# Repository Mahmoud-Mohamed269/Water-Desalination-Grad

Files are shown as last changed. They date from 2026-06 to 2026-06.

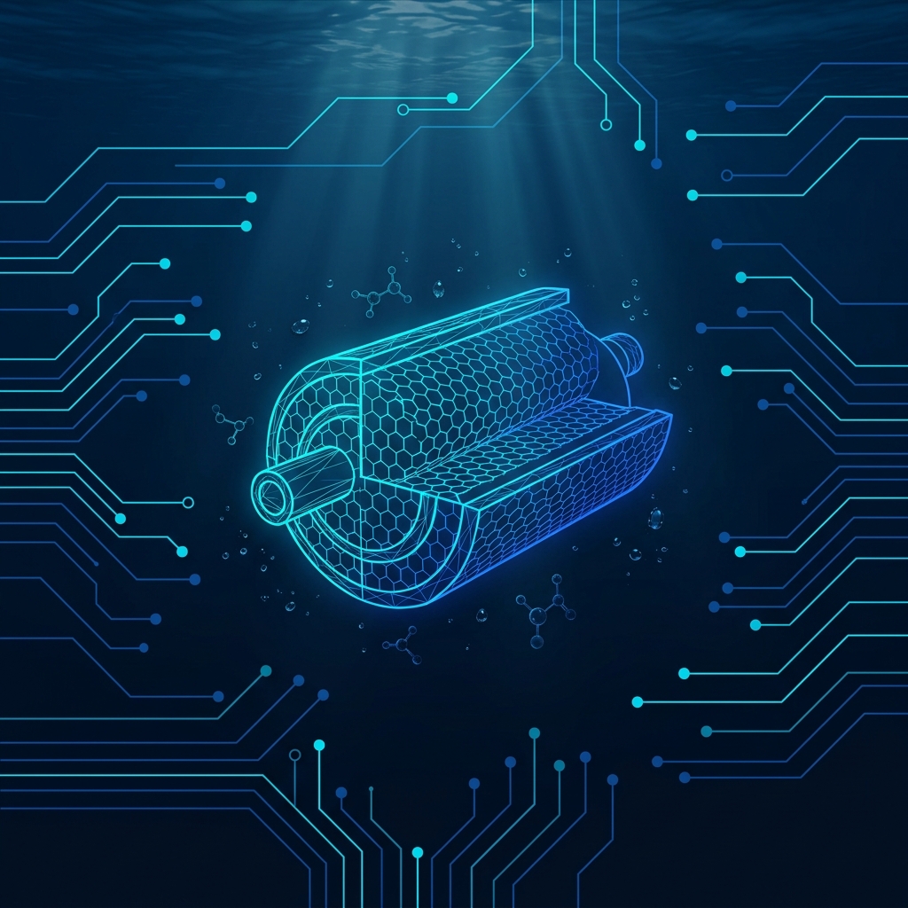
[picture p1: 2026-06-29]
dashboard/src/assets/images/dashboard_bg.png

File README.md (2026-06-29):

# 🌊 AquaMonitor — Smart Water Desalination Monitoring System

A full-stack IoT monitoring and analytics platform for Reverse Osmosis (RO) desalination systems. Combines ESP32 edge nodes, Firebase real-time cloud storage, a FastAPI ML backend, a web dashboard, and a cross-platform mobile app.

---

## 🏗️ System Architecture

```
┌─────────────┐   ESP-NOW    ┌──────────────┐   Firebase RTDB   ┌─────────────┐
│  Node 1     │ ──────────── │   Main Hub   │ ────────────────── │   Firebase  │
│  (Water Q.) │              │   (ESP32)    │                    │  Realtime   │
│  Node 2     │              │              │                    │  Database   │
│  (Environ.) │              └──────┬───────┘                    └──────┬──────┘
└─────────────┘                     │ BLE                               │
                              ┌─────▼──────┐                     ┌──────▼──────┐
                              │ Mobile App │  ←── HTTP sync ────▶│  FastAPI    │
                              │  (Python/  │                      │  Backend    │
                              │   Flet)    │                      │  + ML Models│
                              └────────────┘                      └──────┬──────┘
                                                                         │
                                                                  ┌──────▼──────┐
                                                                  │    Web      │
                                                                  │  Dashboard  │
                                                                  │  (HTML/JS)  │
                                                                  └─────────────┘
```

---

## 📁 Project Structure

```
Water Desalination/
├── Node1_WaterQuality/     # ESP32 firmware — pH, TDS, turbidity, pressure, flow
├── Node2_Environment/      # ESP32 firmware — temperature, humidity, gas, ultrasonic
├── Main_Hub/               # ESP32 firmware — ESP-NOW receiver, BLE server, Firebase uploader
├── backend/                # FastAPI backend — ML predictions, alerts, Firebase proxy
│   ├── app/api/v1/         # REST endpoints (sensors, predict, alerts, chat, status)
│   ├── app/core/           # Config, Firebase client, security
│   ├── app/services/       # ML inference service
│   ├── ml/                 # Trained .pkl model files
│   ├── Procfile            # Railway deployment
│   └── railway.json        # Railway config
├── dashboard/web/          # Web dashboard (HTML + CSS + JS, Firebase direct)
├── mobile/src/             # Flet mobile app (Python)
│   ├── pages/              # Live, History, Alerts, WiFi, Settings
│   ├── ble/                # Real + Virtual BLE client
│   └── db/                 # SQLite offline storage + sync
└── Water Desalination.html # Standalone single-file web dashboard
```

---

## 🔧 Hardware (Bill of Materials)

| Component | Model | Qty | Node |
|---|---|---|---|
| Microcontroller | ESP32 38-pin | 3 | All |
| pH Sensor | Analog pH Kit (BNC) | 2 | Node 1 (feed + permeate) |
| TDS Sensor | TDS Meter V1.0 | 2 | Node 1 (feed + permeate) |
| Turbidity Sensor | Analog module | 1 | Node 1 |
| Pressure Sensor | G1/4 0–1.2 MPa analog | 1 | Node 1 |
| Temperature Sensor | DS18B20 | 2 | Node 1 |
| Flow Sensor | YF-S201 | 2 | Node 1 (feed + permeate) |
| Water Level Sensor | XKC-Y25 (non-contact) | 2 | Node 1 |
| Relay Module | 2-channel 5V | 1 | Node 1 (pump + valve) |
| Temp + Humidity | DHT22 | 1 | Node 2 |
| Gas Sensor | MQ series | 2 | Node 2 |
| Ultrasonic | HC-SR04 | 2 | Node 2 |
| TFT Display | 5" SPI | 1 | Main Hub |

---

## 🚀 Setup Instructions

### 1. Firebase Setup
1. Create a project at [console.firebase.google.com](https://console.firebase.google.com)
2. Enable **Realtime Database** (Europe West region)
3. Download the **service account JSON** → save as `backend/serviceAccountKey.json`
4. Copy your database URL to `backend/.env`:
   ```
   FIREBASE_DATABASE_URL=https://your-project-rtdb.europe-west1.firebasedatabase.app
   ```

### 2. Flash Hardware
```bash
# In Arduino IDE:
# 1. Flash Main_Hub to the hub ESP32 first — note its MAC address from Serial Monitor
# 2. Update hubAddress in Node1/config.h and Node2/config.h
# 3. Flash Node 1 and Node 2
# 4. Open Serial Monitor (115200 baud) — you should see:
#    [ESP-NOW] Node 1 data received
#    [Firebase] Live data pushed OK
```

### 3. Run the Backend
```bash
cd backend
pip install -r requirements.txt
uvicorn main:app --reload
# API docs: http://127.0.0.1:8000/docs
```

### 4. Open the Web Dashboard
```bash
# Option A — standalone file (no server needed):
open "Water Desalination.html"

# Option B — from the dashboard folder:
open dashboard/web/index.html
```

### 5. Run the Mobile App
```bash
cd mobile/src
pip install flet bleak requests
python main.py
```
- Use **Settings** tab to toggle Virtual BLE (for testing without hardware)
- Use **WiFi** tab to provision WiFi credentials to the Hub over BLE

---

## ☁️ Cloud Deployment (Vercel)

Full step-by-step guide: **[phase10_cloud_deployment.md](phase10_cloud_deployment.md)**

### Quick Summary

**1. Encode your Firebase service account as base64 (PowerShell):**
```powershell
[Convert]::ToBase64String([IO.File]::ReadAllBytes("backend\serviceAccountKey.json")) | Set-Clipboard
```

**2. Push to GitHub, then import to [vercel.com](https://vercel.com):**
- Set Root Directory → `backend`
- Framework Preset → `Other`

**3. Add these Environment Variables in Vercel:**
| Variable | Value |
|---|---|
| `FIREBASE_DATABASE_URL` | Your Firebase RTDB URL |
| `FIREBASE_SERVICE_ACCOUNT_BASE64` | Paste the base64 string from step 1 |
| `GEMINI_API_KEY` | Your Gemini API key |
| `API_KEY` | Your chosen API key |

**4. Deploy → get your URL → update mobile app Settings.**

> See [phase10_cloud_deployment.md](phase10_cloud_deployment.md) for the full tutorial including verification steps and troubleshooting.

---

## 🔐 Security

| Layer | Mechanism |
|---|---|
| Backend write endpoints | `X-API-Key` header required |
| Firebase Database | Security Rules (auth-gated in production) |
| Secrets | `.env` file only — `.gitignore`'d |
| CORS | Restricted to known origins |

The API key is set via `API_KEY` in `backend/.env`. The mobile app and ESP32 Hub include it in `X-API-Key` headers for POST requests.

---

## 🤖 ML Models

Two Random Forest models trained on synthetic RO system data:

| Model | Output | File |
|---|---|---|
| Water Quality Classifier | good / acceptable / poor / bad | `water_quality_rf.pkl` |
| Membrane Status Classifier | good / warning / critical / fouled | `membrane_status_rf.pkl` |

**Input features (13):** pH before/after, TDS before/after, Turbidity before/after, Temperature before/after, Pressure, Efficiency (recovery rate), TDS Reduction %, Turbidity Reduction %, pH Change.

**Auto-prediction endpoint:** `GET /api/v1/predict/run` — fetches live Firebase data and derives all features automatically. Call it from the mobile app's Dashboard → ML Analysis → ↻ button.

---

## 📡 API Reference

| Method | Endpoint | Auth | Description |
|---|---|---|---|
| GET | `/api/v1/sensors/live` | Public | Latest live sensor snapshot |
| GET | `/api/v1/sensors/history` | Public | Last N historical readings |
| POST | `/api/v1/sensors/ingest` | API Key | Push sensor data to Firebase |
| GET | `/api/v1/predict/run` | Public | Auto-run ML from live data |
| POST | `/api/v1/predict/` | Public | Manual ML prediction |
| GET | `/api/v1/alerts/history` | Public | Recent alerts |
| POST | `/api/v1/alerts/evaluate` | Public | Evaluate snapshot against thresholds |
| POST | `/api/v1/chat/` | Public | Gemini AI chatbot |
| GET | `/api/v1/status/` | Public | System health |

Full interactive docs: `http://127.0.0.1:8000/docs`

---

## 🛠️ Development

```bash
# Backend tests
cd backend
python -m pytest

# Mobile app (desktop mode)
cd mobile/src
python main.py

# Generate synthetic training data
python generate_data.py

# Retrain ML models
python ML_models.py
```

---

## 📋 Phase Completion Status

| Phase | Description | Status |
|---|---|---|
| 1 | Requirements & Architecture | ✅ |
| 2 | Hardware Design & BOM | ✅ |
| 3 | ESP32 Firmware | ✅ |
| 4 | FastAPI Backend + ML | ✅ |
| 5 | Deployment Guide | ✅ |
| 6 | Hardware Assembly & Real Testing | ✅ Node 1 + Hub verified |
| 8 | Mobile App Polish | ✅ |
| 9 | Security (API Key) | ✅ |
| 10 | Cloud Deployment (Railway) | ⏳ Ready to deploy |
| 11 | Documentation | ✅ |

---

## 👥 Team

Built as part of the TVI Water Desalination Monitoring Project.

---

*Last updated: June 2026*

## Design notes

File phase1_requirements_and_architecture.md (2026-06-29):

# 🌊 Smart Water Desalination Monitoring & Analytics System
## Phase 1 — Requirements Analysis and System Architecture

> [!NOTE]
> **Design Decisions Log** (Updated after user review)
> - ✅ ML Dataset: Will be synthetically generated in Phase 11 (no real dataset required to start)
> - ✅ Flow Sensor (YF-S201): Included — required for Recovery Rate calculation and pump failure detection
> - ✅ Solenoid Valve: Included — enables automated safety shutoff and remote control
> - ✅ Power Mode: Battery/Solar — ESP32 uses Deep Sleep with dual wake sources (water level sensor + dashboard command)

---

## 📋 Table of Contents

1. [Objectives](#objectives)
2. [Theory](#theory)
3. [Detailed System Explanation](#detailed-system-explanation)
4. [System Architecture Design](#system-architecture-design)
5. [Technology Stack Justification](#technology-stack-justification)
6. [Firebase Database Schema](#firebase-database-schema)
7. [Folder Structure](#folder-structure)
8. [Data Flow Diagram](#data-flow-diagram)
9. [Sensor Specifications & Requirements](#sensor-specifications--requirements)
10. [Non-Functional Requirements](#non-functional-requirements)
11. [Validation Checklist](#validation-checklist)
12. [Common Errors & Troubleshooting](#common-errors--troubleshooting)
13. [Best Practices](#best-practices)

---

## 1. Objectives

| # | Objective | Priority |
|---|---|---|
| 1 | Define all functional and non-functional system requirements | 🔴 Critical |
| 2 | Design the complete multi-layer system architecture | 🔴 Critical |
| 3 | Define sensor data models and measurement ranges | 🔴 Critical |
| 4 | Design the Firebase Realtime Database schema | 🔴 Critical |
| 5 | Define the project folder structure (monorepo) | 🔴 Critical |
| 6 | Define communication protocols between all layers | 🟠 High |
| 7 | Establish data quality and filtering requirements | 🟠 High |
| 8 | Define ML prediction targets and thresholds | 🟠 High |
| 9 | Establish security and authentication model | 🟡 Medium |
| 10 | Define deployment strategy per component | 🟡 Medium |

---

## 2. Theory

### 2.1 Reverse Osmosis (RO) Desalination — Engineering Overview

Reverse Osmosis is a pressure-driven membrane separation process. Feed water is pushed through a semi-permeable membrane that rejects dissolved solids, ions, and organic molecules, producing permeate (purified water) and concentrate (brine reject).

**Key Physical Parameters:**

| Parameter | Symbol | Unit | Role in RO |
|---|---|---|---|
| pH | pH | 0–14 | Membrane longevity, scaling potential |
| TDS | TDS | mg/L (ppm) | Rejection efficiency measurement |
| Turbidity | NTU | NTU | Pre-filter fouling, feed quality |
| Temperature | T | °C | Membrane permeability, reaction kinetics |
| Pressure | P | bar / PSI | Driving force for permeation |
| Flow Rate | Q | L/min | Recovery rate, system throughput — **Required for efficiency calculations** |
| Water Level | L | % / cm | Tank management, feed availability — **Also used as wake/sleep trigger** |
| EC (Optional) | EC | µS/cm | Salinity proxy, conductivity |

**Critical RO Ratios:**

```
Recovery Rate (%) = (Permeate Flow / Feed Flow) × 100       ← Requires YF-S201 Flow Sensor
Rejection Rate (%) = (1 - Permeate TDS / Feed TDS) × 100   ← Requires TDS Sensor
Salt Passage (%) = (Permeate TDS / Feed TDS) × 100
```

> **Why the Flow Sensor is non-negotiable:** Recovery Rate is the primary KPI of any RO system. Without it, you cannot determine if your system is operating efficiently or if the membrane is degrading. The YF-S201 (~$3) is the cheapest and most impactful sensor in the system.

> **Why the Solenoid Valve is essential for automation:** Without the solenoid valve, your system can only *alert* you to problems. With it, the system can automatically *respond* — for example, immediately closing when TDS spikes above safe levels, protecting downstream equipment and users. This is the difference between a monitoring system and a control system.

**Typical Target Values for Potable Water (WHO Standards):**

| Parameter | Acceptable Range | Alert Threshold |
|---|---|---|
| pH | 6.5 – 8.5 | < 6.0 or > 9.0 |
| TDS | < 500 mg/L | > 1000 mg/L |
| Turbidity | < 1 NTU | > 4 NTU |
| Temperature | 5 – 30°C | > 40°C |
| Pressure (Feed) | 3 – 8 bar | > 10 bar |

### 2.2 IoT Architecture Patterns

This system uses the **Edge-to-Cloud** IoT architecture:

```
Edge Layer     →   Transport Layer   →   Cloud Layer   →   Application Layer
(ESP32 + Sensors)  (WiFi + MQTT/HTTP)  (Firebase)      (FastAPI + Flet + ML)
```

**Why Edge-to-Cloud?**
- ESP32 handles local data acquisition and preliminary filtering
- Cloud handles persistence, analytics, and multi-client access
- Application layer handles visualization, AI, and prediction

### 2.3 Machine Learning in Water Quality

Random Forest is chosen because:
- Handles non-linear relationships between sensor parameters
- Robust to outliers (critical when sensors malfunction)
- Provides feature importance (explains WHY a prediction was made)
- Works well with tabular sensor data
- Low inference latency (<1ms for 100 trees on sensor data)
- scikit-learn implementation is production-ready

> [!IMPORTANT]
> **No real dataset available at project start.** A realistic synthetic dataset will be generated in Phase 11 using:
> - RO membrane physics equations (rejection rate curves, fouling models)
> - WHO and EPA water quality standards as label boundaries
> - Gaussian sensor noise injection (based on datasheet accuracy specs)
> - Fault scenario injection (membrane fouling, sensor drift, pump cavitation)
> - The synthetic dataset will be used for initial training, then the model will be retrained and fine-tuned using real data collected by the system after deployment.

---

## 3. Detailed System Explanation

### 3.1 System Layers

```mermaid
graph TD
    subgraph "Layer 1: Physical / Sensing Layer (Edge Nodes)"
        S1[Node 1: Water Quality]
        S2[Node 2: Environment]
    end

    subgraph "Layer 2: Local Hub Layer (Main ESP32)"
        Hub[Main Hub: Comms & Display]
    end

    subgraph "Layer 3: Mobile / Offline Layer"
        App[Flet Mobile App]
        LocalDB[(SQLite Local DB)]
    end

    subgraph "Layer 4: Cloud Data Layer"
        FB[(Firebase Realtime DB)]
    end

    subgraph "Layer 5: Backend / API Layer (FastAPI)"
        API[FastAPI + ML Models]
    end

    S1 -- "ESP-NOW (Broadcast)" --> Hub
    S2 -- "ESP-NOW (Broadcast)" --> Hub
    Hub -- "BLE (Offline Sync)" --> App
    Hub -- "WiFi (Live Upload)" --> FB
    App -- "Local Storage" --> LocalDB
    App -- "WiFi (Background Sync)" --> API
    API -- "Ingest / Read" --> FB
```

### 3.2 ESP32 Pin Assignment Plan

> [!NOTE]
> This is the high-level plan for the 3-node architecture. Full pinouts will be finalized in Phase 2 (Hardware Design).

**Node 1 (Water Quality - ESP32 38-pin):**
- pH Feed & Permeate (GPIO34=pH Feed, GPIO36=pH Permeate) — ADC1 only
- TDS Feed & Permeate (GPIO35=TDS Feed, GPIO39=TDS Permeate) — ADC1 only
- Turbidity Feed (GPIO32) — ADC1 only, via 10kΩ/20kΩ voltage divider
- Pressure Feed / G1/4 (GPIO33) — ADC1 only, via 10kΩ/20kΩ voltage divider
- Temperature Feed & Permeate (GPIO4, DS18B20 shared OneWire bus)
- Flow Sensor Feed (GPIO18, interrupt), Flow Permeate (GPIO27, digital interrupt only — ADC2 pin but NOT used for analogRead, safe with WiFi)
- Level Sensors: Feed (GPIO5), Product (GPIO19)
- Relays: Pump (GPIO26), Valve (GPIO25)

**Node 2 (Environment & Fans - ESP32 38-pin):**
- 2x Ultrasonic (Trig/Echo digital pins)
- 1x DHT22 (Digital pin)
- 2x Gas Sensors (ADC1 pins)
- 2x Water Temp (DS18B20 on GPIO4)
- 3x Fans (Relay output pins)

**Main Hub (Display & Comms - ESP32 38-pin):**
- 5-inch SPI TFT Display (MOSI, SCK, CS, DC, RST)
- No analog sensors attached (avoids WiFi/ADC2 conflicts entirely)

> [!IMPORTANT]
> **Mobile App Offline Sync Architecture**
> - The Main ESP32 constantly streams data to the Mobile App via BLE.
> - The App stores data in a local SQLite DB.
> - When internet is available, the App syncs the local DB to Firebase, ensuring zero data loss during WiFi outages.

---

## 4. System Architecture Design

### 4.1 Communication Flowcharts

**Main Hub (Display & Comms) Flowchart**
```mermaid
graph TD
    Start((Start)) --> Init[Init WiFi, NTP, BLE, ESP-NOW, Firebase]
    Init --> ReceiveLoop
    
    ReceiveLoop[Listen for ESP-NOW from Nodes 1 & 2] --> |Data Received| Merge[Merge into JSON Payload]
    Merge --> UpdateDisplay[Update LCD Display]
    UpdateDisplay --> CheckApp{Mobile App Connected via BLE?}
    
    CheckApp -->|Yes| SendBLE[Stream JSON to App]
    CheckApp -->|No| CheckWiFi{WiFi Connected?}
    
    SendBLE --> CheckWiFi
    CheckWiFi -->|Yes| Sync[Upload JSON directly to Firebase RTDB]
    CheckWiFi -->|No| ReceiveLoop
    Sync --> ReceiveLoop
```

**Mobile App (Offline Sync) Flowchart**
```mermaid
graph TD
    Start((App Open)) --> ConnectBLE[Connect to Main Hub via BLE]
    ConnectBLE --> ReceiveData[Receive Merged JSON Data]
    ReceiveData --> StoreLocal[(Store in Local SQLite DB)]
    StoreLocal --> CheckNet{Phone has Internet?}
    
    CheckNet -->|Yes| Sync[Upload Pending Data to FastAPI Backend]
    Sync --> ReceiveData
    CheckNet -->|No| ReceiveData
```

### 4.2 Communication Protocols

| Layer | Protocol | Format | Frequency |
|---|---|---|---|
| Nodes → Main Hub | ESP-NOW | C-Struct | Every 5 sec |
| Main Hub → App | Bluetooth (BLE) | JSON | Every 3 sec |
| Main Hub → Firebase | HTTP / RTDB | JSON | Every 5 sec |
| App → Backend | HTTP POST | JSON | Background Sync |
| Backend → Firebase | Firebase Admin SDK | JSON | On-demand / ingest |
| FastAPI → Dashboard | HTTP GET/POST | JSON | Real-time polling |
| Backend → Gemini | HTTPS | JSON | On-demand chatbot |
| FastAPI → ML Service | Internal Python | Array | On-demand prediction |

---

## 5. Technology Stack Justification

### 5.1 Why ESP32S?
- Dual-core Xtensa LX6 @ 240 MHz — handles sensor reading + WiFi simultaneously
- Built-in WiFi + Bluetooth
- 18 ADC channels (we use ADC1 only during WiFi)
- 4MB flash, 520KB SRAM — sufficient for firmware + buffers
- Low cost, wide community support

### 5.2 Why Firebase Realtime Database?
- Real-time push to all connected clients simultaneously
- JSON tree structure maps naturally to sensor readings
- Built-in security rules
- Free tier: 1GB storage, 10GB/month transfer
- Native SDK for Python, JavaScript, mobile

### 5.3 Why FastAPI?
- Async-first (handles concurrent sensor reads + client requests)
- Auto-generates OpenAPI documentation
- Native Pydantic validation (enforces data schemas)
- Easy ML model integration (Python-native)
- High performance (comparable to Node.js)

### 5.4 Why Flet?
- Write once, run on Web + Android + iOS + Desktop (Python)
- Flutter rendering engine → native-quality UI
- Firebase integration via Python SDK
- Shared codebase for dashboard and mobile app

### 5.5 Why Random Forest?
- No need for feature scaling (unlike SVM, neural nets)
- Interpretable (feature importance)
- Handles missing data gracefully
- Fast inference (<1ms for 100 trees on sensor data)
- scikit-learn implementation is production-ready

### 5.6 Why Google Gemini API?
- Multimodal (can interpret sensor charts + text)
- Domain knowledge of water treatment
- Structured output support (JSON responses)
- Function calling (can query Firebase directly)

---

## 6. Firebase Database Schema

### 6.1 Complete Schema Design

```json
{
  "devices": {
    "device_001": {
      "info": {
        "name": "RO Unit Alpha",
        "location": "Plant A - Zone 1",
        "firmware_version": "1.0.0",
        "registered_at": "2024-01-01T00:00:00Z",
        "last_seen": "2024-01-01T12:00:00Z",
        "status": "online"
      },
      "config": {
        "sampling_interval_ms": 5000,
        "alert_thresholds": {
          "ph_min": 6.5,
          "ph_max": 8.5,
          "tds_max": 1000,
          "turbidity_max": 4.0,
          "temperature_max": 40.0,
          "pressure_max": 10.0,
          "flow_rate_min": 0.5
        },
        "filtering": {
          "algorithm": "kalman",
          "window_size": 10
        }
      },
      "live_data": {
        "ph_feed": 7.2,
        "ph_permeate": 6.9,
        "tds_feed": 850,
        "tds_permeate": 12,
        "turbidity_feed": 0.8,
        "temperature_feed": 24.5,
        "temperature_permeate": 24.2,
        "pressure_feed": 4.2,
        "flow_rate_feed": 2.5,
        "flow_rate_permeate": 1.8,
        "recovery_rate": 72.0,
        "rejection_rate": 98.6,
        "water_level_feed_tank": 100,
        "water_level_product_tank": 0,
        "pump_status": "running",
        "valve_status": "open",
        "tank1_level_cm": 45.5,
        "tank2_level_cm": 20.0,
        "ambient_temp": 32.0,
        "ambient_humidity": 65.0,
        "gas_1_ppm": 400.0,
        "gas_2_ppm": 350.0,
        "water_temp_1": 25.0,
        "water_temp_2": 26.0,
        "fan_1_status": true,
        "fan_2_status": false,
        "fan_3_status": false,
        "timestamp": "2024-01-01T12:00:00Z",
        "uptime_seconds": 3600
      },
      "calibration": {
        "ph": {
          "slope": 1.023,
          "offset": -0.15,
          "temp_coefficient": 0.0198,
          "calibrated_at": "2024-01-01T00:00:00Z",
          "next_calibration_due": "2024-04-01T00:00:00Z"
        },
        "tds": {
          "temp_coefficient": 0.02,
          "calibration_ppm": 1413,
          "calibrated_at": "2024-01-01T00:00:00Z"
        },
        "turbidity": {
          "voltage_at_0_ntu": 4.2,
          "slope": -1120.4,
          "calibrated_at": "2024-01-01T00:00:00Z"
        },
        "pressure": {
          "offset_voltage": 0.5,
          "full_scale_voltage": 4.5,
          "max_pressure_bar": 12.0,
          "calibrated_at": "2024-01-01T00:00:00Z"
        }
      }
    }
  },

  "historical_logs": {
    "device_001": {
      "2024-01-01": {
        "log_001": {
          "ph": 7.2,
          "tds": 320,
          "turbidity": 0.8,
          "temperature": 24.5,
          "pressure_feed": 4.2,
          "flow_rate_feed": 2.5,
          "water_level_feed_tank": 85,
          "recovery_rate": 72.0,
          "rejection_rate": 98.5,
          "timestamp": "2024-01-01T00:00:00Z"
        }
      }
    }
  },

  "alerts": {
    "device_001": {
      "alert_001": {
        "type": "high_tds",
        "severity": "warning",
        "parameter": "tds",
        "value": 1050,
        "threshold": 1000,
        "message": "TDS exceeded maximum threshold (1050 > 1000 ppm)",
        "timestamp": "2024-01-01T12:05:00Z",
        "acknowledged": false,
        "acknowledged_by": null,
        "acknowledged_at": null,
        "resolved": false,
        "resolved_at": null
      }
    }
  },

  "predictions": {
    "device_001": {
      "latest": {
        "water_quality_score": 87.5,
        "water_quality_class": "good",
        "membrane_fouling_risk": "low",
        "membrane_fouling_probability": 0.12,
        "filter_replacement_days": 45,
        "pump_failure_probability": 0.03,
        "sensor_anomalies": [],
        "confidence": 0.94,
        "model_version": "v1.2.0",
        "predicted_at": "2024-01-01T12:00:00Z"
      },
      "history": {
        "2024-01-01": {
          "pred_001": {
            "water_quality_score": 87.5,
            "water_quality_class": "good",
            "membrane_fouling_risk": "low",
            "predicted_at": "2024-01-01T12:00:00Z"
          }
        }
      }
    }
  },

  "system_status": {
    "device_001": {
      "online": true,
      "wifi_rssi": -65,
      "heap_free_bytes": 245760,
      "cpu_temp_celsius": 42.5,
      "loop_frequency_hz": 10,
    "sensor_health": {
        "ph": "ok",
        "tds": "ok",
        "turbidity": "ok",
        "temperature": "ok",
        "pressure": "ok",
        "flow": "ok",
        "level": "ok"
      },
      "last_update": "2024-01-01T12:00:00Z"
    }
  },

  "maintenance_logs": {
    "device_001": {
      "maint_001": {
        "type": "membrane_replacement",
        "description": "RO membrane replaced (DOW FilmTec TW30-1812-50)",
        "performed_by": "Technician A",
        "performed_at": "2024-01-01T00:00:00Z",
        "next_due_at": "2025-01-01T00:00:00Z",
        "cost_usd": 45.00,
        "notes": "Pre-filter also cleaned"
      }
    }
  },

  "users": {
    "user_001": {
      "email": "operator@plant.com",
      "role": "operator",
      "devices": ["device_001"],
      "notification_preferences": {
        "email": true,
        "push": true,
        "sms": false
      }
    }
  }
}
```

### 6.2 Firebase Security Rules (Draft)

```json
{
  "rules": {
    "devices": {
      "$device_id": {
        ".read": "auth != null && root.child('users').child(auth.uid).child('devices').hasChild($device_id)",
        ".write": "auth != null && root.child('users').child(auth.uid).child('role').val() === 'admin'",
        "live_data": {
          ".write": "auth != null"
        }
      }
    },
    "historical_logs": {
      "$device_id": {
        ".read": "auth != null",
        ".write": "auth != null"
      }
    },
    "alerts": {
      "$device_id": {
        ".read": "auth != null",
        ".write": "auth != null"
      }
    },
    "predictions": {
      ".read": "auth != null",
      ".write": "auth != null"
    },
    "system_status": {
      ".read": "auth != null",
      ".write": "auth != null"
    },
    "maintenance_logs": {
      ".read": "auth != null",
      ".write": "auth != null && root.child('users').child(auth.uid).child('role').val() !== 'viewer'"
    }
  }
}
```

---

## 7. Folder Structure

### 7.1 Monorepo Project Structure

```
water-desalination-system/
│
├── 📁 Node1_WaterQuality/              # Edge Node 1 Firmware
│   ├── Node1_WaterQuality.ino
│   ├── config.h
│   ├── state_machine.h / .cpp
│   ├── sensors.h / .cpp
│   └── espnow_broadcast.h / .cpp
│
├── 📁 Node2_Environment/               # Edge Node 2 Firmware
│   ├── Node2_Environment.ino
│   ├── config.h
│   ├── sensors_env.h / .cpp
│   └── espnow_env.h / .cpp
│
├── 📁 Main_Hub/                        # Central Hub Firmware
│   ├── Main_Hub.ino
│   ├── config.h
│   ├── firebase_client.h / .cpp        # Direct RTDB uploads
│   └── ... (BLE and Display handling)
│
├── 📁 backend/                         # FastAPI Backend
│   ├── 📁 app/
│   │   ├── main.py                     # FastAPI app factory
│   │   ├── 📁 api/
│   │   │   └── 📁 v1/
│   │   │       ├── sensors.py          # Data endpoints
│   │   │       ├── predictions.py      # ML models
│   │   │       └── chat.py             # Gemini chatbot
│   │   ├── 📁 core/
│   │   │   ├── config.py               
│   │   │   └── firebase.py             
│   │   └── 📁 services/
│   │       └── alert_engine.py         
│   ├── run.py
│   └── requirements.txt
│
├── 📁 dashboard/                       # Web UI
│   └── 📁 web/
│       ├── index.html
│       ├── style.css
│       └── app.js
│
├── 📁 mobile/                          # Flet Mobile App
│   ├── 📁 src/
│   │   ├── main.py                     # Entry point, bottom nav
│   │   ├── 📁 pages/
│   │   │   ├── dashboard.py
│   │   │   ├── history.py
│   │   │   ├── wifi_setup.py
│   │   │   └── settings.py
│   │   ├── 📁 ble/
│   │   │   └── client.py               # Real & Virtual BLE
│   │   └── 📁 db/
│   │       ├── local_db.py             # SQLite offline storage
│   │       └── sync.py                 # Background upload to backend
│   └── requirements.txt
```
├── 📁 ml/                              # Standalone ML Development
│   ├── 📁 notebooks/
│   │   ├── 01_data_exploration.ipynb
│   │   ├── 02_feature_engineering.ipynb
│   │   ├── 03_model_training.ipynb
│   │   ├── 04_hyperparameter_tuning.ipynb
│   │   └── 05_model_evaluation.ipynb
│   ├── 📁 data/
│   │   ├── 📁 raw/                     # Raw collected sensor data
│   │   ├── 📁 processed/               # Cleaned and feature-engineered data
│   │   └── 📁 synthetic/              # Synthetic data for initial training
│   ├── 📁 models/                      # Trained model artifacts
│   ├── generate_synthetic_data.py
│   ├── train_pipeline.py
│   └── requirements.txt
│
├── 📁 docs/                            # Project Documentation
│   ├── 📁 phases/                      # Per-phase documentation
│   │   ├── phase01_requirements.md
│   │   ├── phase02_hardware.md
│   │   └── ...
│   ├── 📁 api/                         # API documentation
│   ├── 📁 hardware/
│   │   ├── schematic.pdf
│   │   ├── pin_assignment.md
│   │   └── bom.md                      # Bill of Materials
│   └── architecture.md
│
├── 📁 scripts/                         # Utility Scripts
│   ├── setup_firebase.py               # Firebase initialization script
│   ├── generate_test_data.py           # Test data generator
│   ├── deploy.sh                       # Deployment automation
│   └── calibrate_sensors.py            # CLI calibration tool
│
├── .gitignore
├── README.md
└── docker-compose.yml                  # Local development stack
```

---

## 8. Data Flow Diagram

```
┌──────────┐   ESP-NOW     ┌──────────────┐   RTDB Push    ┌────────────┐
│  Sensor  │ ─────────────▶│   Main Hub   │ ──────────────▶│  Firebase  │
│ Nodes 1,2│               │  (ESP32S)    │   (WiFi)       │  Realtime  │
└──────────┘               └──────┬───────┘                │  Database  │
                                  │                        └──────┬─────┘
                                  ▼ BLE                           │
                           ┌──────────────┐                       │ REST/SDK Pull
                           │  Mobile App  │                       ▼
                           │ (Local DB)   │                ┌─────────────┐
                           └──────┬───────┘                │   FastAPI   │
                                  │ HTTP Sync              │   Backend   │
                                  └───────────────────────▶└──────┬──────┘
                                                                  │
                                                      ┌───────────┴───────────┐
                                                      │                       │
                                                      ▼                       ▼
                                               ┌─────────────┐        ┌─────────────┐
                                               │  ML Service │        │ Gemini API  │
                                               │  (sklearn)  │        │  (Google)   │
                                               └──────┬──────┘        └──────┬──────┘
                                                      │                      │
                                                      └──────────┬───────────┘
                                                                 ▼
                                                          Predictions +
                                                          AI Insights
                                                          → Displayed in
                                                          Dashboard/App
```

---

## 9. Sensor Specifications & Requirements

### 9.1 Complete Sensor Reference Table

| Sensor | Model | Range | Output | Resolution | Accuracy | Sampling Rate |
|--------|-------|-------|--------|------------|----------|---------------|
| pH (Feed) | Analog pH Kit | 0–14 pH | 0–3.3V analog | 0.01 pH | ±0.1 pH | 1 Hz |
| pH (Permeate) | Analog pH Kit | 0–14 pH | 0–3.3V analog | 0.01 pH | ±0.1 pH | 1 Hz |
| TDS (Feed) | TDS Meter V1.0 | 0–1000 ppm | 0–2.3V analog | 1 ppm | ±10% | 1 Hz |
| TDS (Permeate) | TDS Meter V1.0 | 0–1000 ppm | 0–2.3V analog | 1 ppm | ±10% | 1 Hz |
| Turbidity | Analog Module | 0–3000 NTU | 0–4.5V analog | 0.1 NTU | ±5% | 1 Hz |
| Temperature | DS18B20 ×2 | -55–125°C | 1-Wire digital | 0.0625°C | ±0.5°C | 0.1 Hz |
| Pressure | G1/4 Analog | 0–1.2 MPa | 0.5–4.5V analog | 0.01 bar | ±2% FS | 1 Hz |
| Water Level | XKC-Y25 ×2 | Contact-free | Digital HIGH/LOW | Binary | N/A | 10 Hz |
| Flow Rate (Feed) | YF-S201 | 1–30 L/min | PWM pulse | 0.1 L/min | ±10% | Interrupt |
| Flow Rate (Permeate) | YF-S201 | 1–30 L/min | PWM pulse | 0.1 L/min | ±10% | Interrupt |

### 9.2 Measurement Frequency Plan

```
High Priority (every 5 seconds, sent to Firebase):
  • pH, TDS, Temperature, Turbidity, Pressure, Flow Rate, Water Level

Medium Priority (logged every 1 minute):
  • Computed metrics: Recovery Rate, Rejection Rate, Running averages

Low Priority (logged every 10 minutes):
  • System diagnostics: WiFi RSSI, Free heap, CPU temp

ML Prediction (every 5 minutes):
  • Triggered by FastAPI service using latest live_data
```

---

## 10. Non-Functional Requirements

| Category | Requirement | Target |
|----------|-------------|--------|
| **Latency** | Sensor-to-dashboard display | < 3 seconds end-to-end |
| **Availability** | System uptime | > 99.5% |
| **Data Retention** | Historical logs | 365 days |
| **Scalability** | Concurrent devices | Up to 50 devices |
| **Security** | Data transport | TLS 1.3 (HTTPS) |
| **Security** | Auth | Firebase Authentication |
| **Accuracy** | ML model F1-score | > 90% on test set |
| **Throughput** | FastAPI requests | > 500 req/sec |
| **Storage** | Firebase usage | < 100MB/device/year |
| **Mobile** | App response time | < 500ms for UI interactions |

---

## 11. Validation Checklist

### ✅ Phase 1 Completion Criteria

#### Architecture & Design
- [ ] Complete system architecture diagram reviewed and approved
- [ ] All system layers defined with clear interfaces
- [ ] Communication protocols selected and documented
- [ ] Data flow verified end-to-end on paper

#### Hardware Planning
- [ ] All sensor models identified and data sheets reviewed
- [ ] ESP32 pin assignment table completed with no conflicts
- [ ] ADC1-only constraint verified for all analog sensors
- [ ] Power supply requirements calculated (3.3V vs 5V per sensor)

#### Firebase
- [ ] Firebase project created in Firebase Console
- [ ] Realtime Database provisioned (us-central1 or nearest region)
- [ ] Database schema designed and documented
- [ ] Security rules drafted
- [ ] Firebase Admin SDK service account created
- [ ] Firebase config keys stored securely (not in code)

#### Software Structure
- [ ] Project repository initialized (Git)
- [ ] Complete folder structure created
- [ ] .gitignore configured (secrets.h, .env, *.pkl excluded)
- [ ] README.md created at project root
- [ ] All technology versions documented

#### Environment Setup
- [ ] Arduino IDE / PlatformIO installed
- [ ] ESP32 board package installed
- [ ] Python 3.11+ installed
- [ ] FastAPI + dependencies listed in requirements.txt
- [ ] Flet 0.80.5 installed
- [ ] Firebase Admin Python SDK installed
- [ ] Google Gemini Python SDK installed
- [ ] scikit-learn installed

---

## 12. Common Errors & Troubleshooting

### 12.1 Firebase Setup Issues

| Error | Cause | Fix |
|-------|-------|-----|
| `PERMISSION_DENIED` | Security rules too restrictive | Set rules to allow authenticated reads temporarily |
| `Database not found` | Wrong database URL format | Must end with `.firebaseio.com` |
| `Service account invalid` | Wrong JSON key file | Download fresh key from Firebase Console → Project Settings → Service Accounts |

### 12.2 ESP32 Planning Issues

| Issue | Cause | Fix |
|-------|-------|-----|
| ADC reading 0 on analog sensors | Using ADC2 pin while WiFi is on | Move all analog sensors to GPIO32-39 (ADC1) |
| Random resets during WiFi | Insufficient power | Use external 5V 2A power supply, not USB alone |
| DS18B20 reads -127°C | Missing pull-up resistor | Add 4.7kΩ between DATA and VCC |

### 12.3 Architecture Decisions

| Decision | Options Considered | Chosen | Reason |
|----------|-------------------|--------|--------|
| Embedded protocol | MQTT vs HTTP | HTTPS POST | Simpler, Firebase-native, no broker needed |
| Database | Firebase vs PostgreSQL | Firebase | Real-time push, mobile-friendly, free tier |
| ML framework | TensorFlow vs sklearn | sklearn RF | Lighter, faster inference, interpretable |
| API style | REST vs GraphQL | REST | Simpler, better ecosystem support |

---

## 13. Best Practices

### 13.1 Security Best Practices
1. **Never commit credentials** — use `.env` files and `secrets.h` (both gitignored)
2. **Use Firebase Security Rules** — never use open read/write
3. **Rotate Firebase service account keys** every 90 days
4. **Use HTTPS only** — never plain HTTP for API endpoints

### 13.2 Code Quality Best Practices
1. **Use semantic versioning** for firmware (MAJOR.MINOR.PATCH)
2. **Document every function** with purpose, params, return values
3. **Use constants for all magic numbers** (pin numbers, thresholds)
4. **Write unit tests** for backend services and ML pipeline

### 13.3 Data Engineering Best Practices
1. **Always timestamp data at the source** (ESP32 NTP-synced clock)
2. **Design for schema evolution** — add fields, never remove
3. **Store raw + filtered readings** for audit trail
4. **Validate data ranges** before storing to Firebase

### 13.4 Hardware Best Practices
1. **Use bypass capacitors** (100nF) near each analog sensor
2. **Use shielded cables** for analog signal lines > 30cm
3. **Separate analog and digital ground planes** if possible
4. **Add TVS diodes** on sensor lines for surge protection

---

## 🚀 Action Items Before Phase 2

> [!IMPORTANT]
> Complete ALL items below before proceeding to Phase 2

### Immediate Setup Tasks

1. **Create Firebase Project**
   - Go to [Firebase Console](https://console.firebase.google.com)
   - Create project: `water-desalination-system`
   - Enable Realtime Database (Start in test mode)
   - Download `serviceAccountKey.json`

2. **Initialize Git Repository**
   ```bash
   mkdir water-desalination-system
   cd water-desalination-system
   git init
   ```

3. **Create the folder structure**
   ```bash
   mkdir -p firmware/src/{sensors,calibration,filters,communication,control,config}
   mkdir -p backend/app/{api/v1,core,models,services,ml/models}
   mkdir -p dashboard/src/{pages,components,services,models,utils,assets}
   mkdir -p mobile/src/{screens,components}
   mkdir -p ml/{notebooks,data/{raw,processed,synthetic},models}
   mkdir -p docs/{phases,api,hardware}
   mkdir scripts
   ```

4. **Install Python Environment**
   ```bash
   python -m venv venv
   venv\Scripts\activate   # Windows
   pip install fastapi uvicorn firebase-admin google-generativeai scikit-learn flet pandas numpy python-dotenv
   ```

5. **Install PlatformIO** (VS Code Extension) or Arduino IDE 2.x with ESP32 board package

---

> [!NOTE]
> **Phase 1 is complete when all validation checklist items are checked ✅**

---

## 📊 Phase Summary

| Item | Status |
|---|---|
| System Architecture | ✅ Designed |
| Database Schema | ✅ Designed |
| Folder Structure | ✅ Defined |
| Technology Stack | ✅ Justified |
| Sensor Specifications | ✅ Documented |
| Non-Functional Requirements | ✅ Defined |
| Security Model | ✅ Drafted |
| Action Items | ⏳ Pending your completion |

---

**Have you completed this phase?**

Reply with **"Phase Completed"** to proceed to **Phase 2: Hardware Design and Connections**.

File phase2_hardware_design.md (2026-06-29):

# 🔧 Phase 2 — Hardware Design and Connections

---

## 📋 Table of Contents

1. [Objectives](#1-objectives)
2. [Theory](#2-theory)
3. [Bill of Materials (BOM)](#3-bill-of-materials-bom)
4. [Power Supply Design](#4-power-supply-design)
5. [ESP32S 38-Pin Board Layout](#5-esp32s-38-pin-board-layout)
6. [Complete Pin Assignment Table](#6-complete-pin-assignment-table)
7. [Voltage Divider Design](#7-voltage-divider-design)
8. [Sensor Wiring Diagrams](#8-sensor-wiring-diagrams)
9. [Complete System Wiring Overview](#9-complete-system-wiring-overview)
10. [Source Code Files](#10-source-code-files)
11. [Testing Procedures](#11-testing-procedures)
12. [Validation Checklist](#12-validation-checklist)
13. [Common Errors & Troubleshooting](#13-common-errors--troubleshooting)
14. [Best Practices](#14-best-practices)

---

## 1. Objectives

| # | Objective |
|---|---|
| 1 | Connect all 7 sensors to the ESP32S safely |
| 2 | Design voltage dividers for 5V sensor outputs |
| 3 | Wire relay modules for pump and solenoid valve control |
| 4 | Design a clean power distribution system |
| 5 | Verify all connections with the hardware test sketch |
| 6 | Create the `config.h` master pin definition file |

---

## 2. Theory

### 2.1 ESP32 ADC Limitation — The Most Critical Rule

The ESP32 has **two ADC units**:

| ADC Unit | Pins | WiFi-Safe? |
|---|---|---|
| **ADC1** | GPIO32, 33, 34, 35, 36, 39 | ✅ YES |
| **ADC2** | GPIO0, 2, 4, 12, 13, 14, 15, 25, 26, 27 | ❌ NO |

> [!CAUTION]
> **ADC2 is internally used by the WiFi radio.** When WiFi is active, any `analogRead()` on ADC2 pins returns garbage values or causes crashes. ALL analog sensors in this project use ADC1 pins only.

### 2.2 Voltage Divider Principle

Several sensors are powered by 5V and output up to 4.5V. The ESP32 ADC maximum input is **3.3V**. Exceeding this **permanently damages** the ESP32.

**Solution: Resistor Voltage Divider**

```
  Sensor Output (5V max)
         │
        [R1 = 10kΩ]
         │
         ├──────────── To ESP32 GPIO (ADC)
         │
        [R2 = 20kΩ]
         │
        GND
```

```
Vout = Vin × R2 / (R1 + R2)
Vout = 5.0 × 20 / (10 + 20)
Vout = 5.0 × 0.667
Vout = 3.33V  ✅ (safe for ESP32)
```

**Affected sensors requiring dividers:**
- Turbidity Sensor (outputs 0–4.5V at 5V supply)
- Pressure Sensor G1/4 (outputs 0.5–4.5V at 5V supply)

### 2.3 OneWire Protocol (DS18B20)

The DS18B20 uses the Dallas OneWire protocol — a single-wire bidirectional communication. A **4.7kΩ pull-up resistor** between the DATA line and VCC is **mandatory**. Without it, the sensor will always return `-127°C` (error code).

### 2.4 Relay Module Logic

Most relay modules are **Active-LOW** (the relay energizes when the control pin is pulled LOW):
- `digitalWrite(PIN_RELAY, LOW)` → Relay **ON** → Pump/Valve ON
- `digitalWrite(PIN_RELAY, HIGH)` → Relay **OFF** → Pump/Valve OFF

The relay module uses an optocoupler for isolation, protecting the ESP32 from the high-current load circuit.

---

## 3. Bill of Materials (BOM)

### 3.1 Core Components

| # | Component | Quantity | Notes |
|---|---|---|---|
| 1 | ESP32 38-pin Development Board | 3 | Main Hub, Node 1, Node 2 |
| 2 | 5-inch SPI TFT LCD Module | 1 | ILI9488 or equivalent SPI display |
| 3 | pH Analog Sensor Kit | 1 | For Node 1 |
| 4 | TDS Meter Analog Sensor | 1 | For Node 1 |
| 5 | Water Turbidity Sensor | 1 | For Node 1 |
| 6 | Analog Water Pressure Sensor | 1 | For Node 1 |
| 7 | XKC-Y25 Level Sensor | 2 | For Node 1 |
| 8 | YF-S201 Water Flow Sensor | 1 | For Node 1 |
| 9 | Ultrasonic Distance Sensor | 2 | For Node 2 (Tank Levels) |
| 10 | DHT22 Temp/Humidity Sensor | 1 | For Node 2 |
| 11 | MQ-Series Gas Sensor | 2 | For Node 2 |
| 12 | DS18B20 Temp Sensor | 2 | For Node 2 |
| 13 | Relay Modules | 5 | 2 for Node 1 (Pump/Valve), 3 for Node 2 (Fans) |
| 14 | RO Pump & Solenoid Valve | 1 ea | Controlled by Node 1 |
| 15 | Cooling Fans (12V) | 3 | Controlled by Node 2 |

### 3.2 Passive Components

| # | Component | Quantity | Value | Purpose |
|---|---|---|---|---|
| 1 | Resistor | 2 | 10kΩ (1%) | Voltage divider R1 |
| 2 | Resistor | 2 | 20kΩ (1%) | Voltage divider R2 |
| 3 | Resistor | 1 | 4.7kΩ | DS18B20 pull-up |
| 4 | Resistor | 1 | 10kΩ | Flow sensor pull-up |
| 5 | Capacitor | 4 | 100nF ceramic | ADC bypass caps |
| 6 | Capacitor | 1 | 10µF electrolytic | 3.3V power line filter |

### 3.3 Power & Wiring

| # | Component | Quantity | Notes |
|---|---|---|---|
| 1 | 5V 2A DC Power Supply | 1 | For ESP32 + all 5V sensors |
| 2 | 12V or 24V 5A DC Power Supply | 1 | For pump + solenoid valve |
| 3 | AMS1117-3.3 Regulator or equivalent | 1 | If needed for 3.3V rail |
| 4 | Terminal blocks (2-pin) | 10 | For sensor wire connections |
| 5 | Breadboard or PCB | 1 | For prototyping |
| 6 | Dupont jumper wires (M-M, M-F, F-F) | 40+ | Various |
| 7 | Shielded wire (for analog sensors) | 2m | Reduces noise |

### 3.4 Arduino Libraries Required

| Library | Author | Install via |
|---|---|---|
| `OneWire` | Paul Stoffregen | Arduino Library Manager |
| `DallasTemperature` | Miles Burton | Arduino Library Manager |
| `ArduinoJson` | Benoit Blanchon | Arduino Library Manager |
| `Firebase ESP Client` | Mobizt | Arduino Library Manager |
| `NTPClient` | Fabrice Weinberg | Arduino Library Manager |

---

## 4. Power Supply Design

### 4.1 Power Budget

| Component | Voltage | Current Draw | Source |
|---|---|---|---|
| ESP32S | 3.3V (via onboard LDO) | 80–250 mA | 5V supply via USB/VIN |
| pH Sensor board | 5V | ~5 mA | 5V rail |
| TDS Sensor board | 3.3–5V | ~3 mA | 3.3V or 5V rail |
| Turbidity Sensor | 5V | ~30 mA | 5V rail |
| DS18B20 | 3.3V | ~1.5 mA | 3.3V rail |
| Pressure Sensor | 5V | ~10 mA | 5V rail |
| XKC-Y25 × 2 | 5–12V | ~15 mA × 2 | 5V rail |
| YF-S201 Flow | 5–12V | ~15 mA | 5V rail |
| Relay Module | 5V (coil) | ~50 mA × 2 | 5V rail |
| **TOTAL 5V load** | **5V** | **~480 mA** | **5V 2A supply** |
| RO Pump | 12V | 3–5 A | 12V supply (separate) |
| Solenoid Valve | 12V | 0.5–1 A | 12V supply (separate) |

### 4.2 Power Distribution Diagram

```
  [5V 2A Power Supply]
         │
         ├─────────────────── ESP32S VIN pin
         │                    (onboard LDO → 3.3V)
         │
         ├─────────────────── pH Sensor VCC (5V)
         │
         ├─────────────────── Turbidity Sensor VCC (5V)
         │
         ├─────────────────── Pressure Sensor VCC (5V)
         │
         ├─────────────────── XKC-Y25 #1 VCC (5V)
         │
         ├─────────────────── XKC-Y25 #2 VCC (5V)
         │
         ├─────────────────── YF-S201 VCC (5V)
         │
         └─────────────────── Relay Module VCC (5V)

  [ESP32S 3.3V pin] ──────── TDS Sensor VCC (3.3V)
                   └──────── DS18B20 VCC (3.3V)

  [12V 5A Power Supply]
         ├─────────────────── Relay Common (COM)
         │                    → Relay NC → Pump
         └─────────────────── Relay Common (COM)
                              → Relay NC → Solenoid Valve

  GND ──────────────────────── ALL GND pins connected together
```

> [!IMPORTANT]
> The 12V pump/valve power supply **shares GND** with the 5V/3.3V circuit but the **12V line itself is isolated** — it only connects to the relay Common (COM) terminal. Never connect 12V directly to the ESP32 or sensors.

---

## 5. ESP32 Board Layouts (3 Nodes)

The system is distributed across three separate ESP32s to prevent GPIO exhaustion and ADC interference.

### 5.1 Node 1: Water Quality (Sensor Node)
```
                    ESP32S 38-PIN BOARD (Node 1)
                    ┌─────────────────┐
              EN ───┤ EN          D23 ├─── (free)
 pH(Perm) GPIO36 ─── ┤ VP(36)      D22 ├─── (free)
 TDS(Perm)GPIO39 ──┤ VN(39)      TX0 ├─── Serial TX
 pH(Feed) GPIO34 ───┤ D34         RX0 ├─── Serial RX
 TDS(Feed)GPIO35 ───┤ D35         D21 ├─── (free)
 TurbidityGPIO32 ───┤ D32         D19 ├────Level Product
 Pressure GPIO33 ───┤ D33         D18 ├────Flow (Feed)
 Valve    GPIO25 ───┤ D25    (TX2)D17 ├─── (free)
 Pump     GPIO26 ──┤ D26    (RX2)D16 ├─── (free)
 Flow(P)  GPIO27 ──┤ D27         D15 ├─── (free)
          GPIO14 ──┤ D14          D2 ├────Status LED
          GPIO12 ──┤ D12          D4 ├────DS18B20 Temp
              GND─ ┤ GND         GND ├─── GND
          GPIO13 ──┤ D13         D5  ├────Level Feed
              5V ─ ┤ 5V          3V3 ├─── 3.3V out
                    └─────────────────┘
```

### 5.2 Node 2: Environment
```
                    ESP32S 38-PIN BOARD (Node 2)
                    ┌─────────────────┐
              EN ───┤ EN          D23 ├─── (free)
 Gas1     GPIO36 ─── ┤ VP(36)      D22 ├─── (free)
 Gas2     GPIO39 ──┤ VN(39)      TX0 ├─── Serial TX
          GPIO34 ───┤ D34         RX0 ├─── Serial RX
          GPIO35 ───┤ D35         D21 ├─── (free)
 Fan3     GPIO32 ───┤ D32         D19 ├─── (free)
          GPIO33 ───┤ D33         D18 ├─── (free)
 Fan1     GPIO25 ───┤ D25    (TX2)D17 ├─── (free)
 Fan2     GPIO26 ──┤ D26    (RX2)D16 ├─── (free)
 US2 Echo GPIO27 ──┤ D27         D15 ├─── (free)
 US2 Trig GPIO14 ──┤ D14          D2 ├────Status LED
 US1 Echo GPIO12 ──┤ D12          D4 ├────DHT22
              GND─ ┤ GND         GND ├─── GND
 US1 Trig GPIO13 ──┤ D13         D5  ├────DS18B20 (Water Temps)
              5V ─ ┤ 5V          3V3 ├─── 3.3V out
                    └─────────────────┘
```

### 5.3 Main Hub (Comms & Display)
```
                    ESP32S 38-PIN BOARD (Main Hub)
                    ┌─────────────────┐
              EN ───┤ EN          D23 ├────TFT MOSI
          GPIO36 ─── ┤ VP(36)      D22 ├────TFT SCL (Touch)
          GPIO39 ──┤ VN(39)      TX0 ├─── Serial TX
          GPIO34 ───┤ D34         RX0 ├─── Serial RX
          GPIO35 ───┤ D35         D21 ├────TFT SDA (Touch)
          GPIO32 ───┤ D32         D19 ├────TFT MISO
          GPIO33 ───┤ D33         D18 ├────TFT SCK
          GPIO25 ───┤ D25    (TX2)D17 ├─── (free)
          GPIO26 ──┤ D26    (RX2)D16 ├─── (free)
          GPIO27 ──┤ D27         D15 ├─── (free)
          GPIO14 ──┤ D14          D2 ├────TFT DC
          GPIO12 ──┤ D12          D4 ├────TFT RST
              GND─ ┤ GND         GND ├─── GND
          GPIO13 ──┤ D13         D5  ├────TFT CS
              5V ─ ┤ 5V          3V3 ├─── 3.3V out
                    └─────────────────┘
```

---

## 6. Complete Pin Assignment Table

### 6.1 Node 1: Water Quality
| Sensor / Module | Pin Name | ESP32 GPIO | Role | Note |
|---|---|---|---|---|
| pH Feed | AOUT | GPIO34 | ADC1 | Use shielded cable |
| pH Permeate | AOUT | GPIO36 | ADC1 | Use shielded cable |
| TDS Feed | AOUT | GPIO35 | ADC1 | |
| TDS Permeate | AOUT | GPIO39 | ADC1 | |
| Turbidity | AOUT | GPIO32 | ADC1 | Voltage divider required |
| Pressure G1/4 | OUT | GPIO33 | ADC1 | Voltage divider required |
| DS18B20 Temps | DATA | GPIO4 | 1W | 4.7kΩ pull-up to 3.3V |
| Flow Feed | SIGNAL | GPIO18 | INT  | 10kΩ pull-up |
| Flow Permeate | SIGNAL | GPIO27 | INT  | 10kΩ pull-up |
| Level Feed | OUT | GPIO5 | IN | XKC-Y25, check for HIGH/LOW |
| Level Product | OUT | GPIO19 | IN | XKC-Y25, check for HIGH/LOW |
| Relay (Pump) | IN | GPIO26 | OUT  | Active-LOW |
| Relay (Valve) | IN | GPIO25 | OUT  | Active-LOW |

### 6.2 Node 2: Environment
| Sensor / Module | Pin Name | ESP32 GPIO | Role | Note |
|---|---|---|---|---|
| Gas 1 | AOUT | GPIO36 | ADC1 | |
| Gas 2 | AOUT | GPIO39 | ADC1 | |
| Ultrasonic 1 | TRIG | GPIO13 | OUT  | Tank 1 |
| Ultrasonic 1 | ECHO | GPIO12 | IN | Tank 1 |
| Ultrasonic 2 | TRIG | GPIO14 | OUT  | Tank 2 |
| Ultrasonic 2 | ECHO | GPIO27 | IN | Tank 2 |
| DHT22 | DATA | GPIO4 | 1W | Environment |
| DS18B20 Temps | DATA | GPIO5 | 1W | Water Temps, shared bus |
| Relay (Fan 1) | IN | GPIO25 | OUT  | Active-LOW |
| Relay (Fan 2) | IN | GPIO26 | OUT  | Active-LOW |
| Relay (Fan 3) | IN | GPIO32 | OUT  | Active-LOW |

### 6.3 Main Hub (Comms & Display)
| Module | Pin Name | ESP32 GPIO | Role | Note |
|---|---|---|---|---|
| TFT SPI Display | CS | GPIO5 | OUT  | Chip Select |
| TFT SPI Display | DC | GPIO2 | OUT  | Data/Command |
| TFT SPI Display | RST | GPIO4 | OUT  | Reset |
| TFT SPI Display | MOSI | GPIO23 | OUT  | SPI Data Out |
| TFT SPI Display | MISO | GPIO19 | IN | SPI Data In |
| TFT SPI Display | SCK | GPIO18 | OUT  | SPI Clock |
| TFT Touch I2C | SDA | GPIO21 | I2C  | Optional Touch |
| TFT Touch I2C | SCL | GPIO22 | I2C  | Optional Touch |

---

## 7. Voltage Divider Design

### 7.1 Turbidity Sensor Voltage Divider

```
  Turbidity Sensor AOUT (0–4.5V)
          │
         [R1 = 10kΩ]
          │
          ├──────── GPIO32 (ADC1_CH4)
          │         Max: 4.5 × 20/30 = 3.0V ✅
         [R2 = 20kΩ]
          │
         GND
```

**Inverse recovery in software:**
```cpp
// After reading ADC voltage (Vout):
float actualVoltage = Vout * VDIV_RATIO_TURBIDITY;  // × 1.5
// actualVoltage now represents the true 0–4.5V sensor output
```

### 7.2 Pressure Sensor Voltage Divider

```
  Pressure Sensor AOUT (0.5–4.5V)
          │
         [R1 = 10kΩ]
          │
          ├──────── GPIO33 (ADC1_CH5)
          │         Max: 4.5 × 20/30 = 3.0V ✅
         [R2 = 20kΩ]
          │
         GND
```

---

## 8. Sensor Wiring Diagrams

### 8.1 pH Sensor

```
  pH Sensor Board                    ESP32S
  ──────────────                     ──────
  VCC ─────────────────────────────── 5V (VIN)
  GND ─────────────────────────────── GND
  AOUT ──────────────[100nF]─── GND  GPIO34
         └───────────────────────────  (ADC1)

  * 100nF capacitor from AOUT to GND: noise bypass
  * Use shielded cable for AOUT line if > 20cm
  * pH Probe connects to BNC connector on sensor board
```

### 8.2 TDS Sensor V1.0

```
  TDS Sensor Board                   ESP32S
  ────────────────                   ──────
  VCC ─────────────────────────────── 3.3V
  GND ─────────────────────────────── GND
  AOUT ──────────────[100nF]─── GND  GPIO35
         └───────────────────────────  (ADC1)

  * TDS sensor outputs max 2.3V — safe for ESP32 directly
  * TDS probe (two stainless electrodes) connects to sensor board
```

### 8.3 Turbidity Sensor (with Voltage Divider)

```
  Turbidity Sensor                   Voltage Divider     ESP32S
  ────────────────                   ───────────────     ──────
  VCC ──────────────────────────────────────────────── 5V
  GND ──────────────────────────────────────────────── GND
  AOUT ─────────────────────── [10kΩ R1]
                                        │
                                        ├──── GPIO32 (ADC1)
                                        │
                               [20kΩ R2]
                                        │
                                       GND
  [100nF bypass cap from GPIO32 to GND]
```

### 8.4 DS18B20 Temperature Sensor

```
  DS18B20 (3-wire)                   ESP32S
  ────────────────                   ──────
  VDD (Red) ───────────────────────── 3.3V
  GND (Black) ─────────────────────── GND
  DATA (Yellow) ──────[4.7kΩ]──────── 3.3V (pull-up)
                  └──────────────────  GPIO4

  * 4.7kΩ pull-up BETWEEN Data and VCC is MANDATORY
  * Without pull-up: sensor always returns -127°C
  * Multiple DS18B20 can share the same GPIO4 (daisy chain)
  * Each sensor has unique 64-bit address for identification
```

### 8.5 Pressure Sensor G1/4 (with Voltage Divider)

```
  Pressure Sensor G1/4               Voltage Divider     ESP32S
  ────────────────────               ───────────────     ──────
  VCC (Red) ─────────────────────────────────────────── 5V
  GND (Black) ───────────────────────────────────────── GND
  AOUT (Yellow) ──────────────[10kΩ R1]
                                          │
                                          ├──── GPIO33 (ADC1)
                                          │
                                 [20kΩ R2]
                                          │
                                         GND
  [100nF bypass cap from GPIO33 to GND]

  Pressure Rating: Install G1/4 fitting on feed line (before membrane)
```

### 8.6 XKC-Y25 Non-Contact Water Level Sensor

```
  XKC-Y25 Sensor #1 (Feed Tank)      ESP32S
  ─────────────────────────────       ──────
  Brown  (VCC) ─────────────────────── 5V
  Blue   (GND) ─────────────────────── GND
  Black  (OUT) ─────────────────────── GPIO5 (INPUT_PULLUP)

  XKC-Y25 Sensor #2 (Product Tank)   ESP32S
  ─────────────────────────────────── ──────
  Brown  (VCC) ─────────────────────── 5V
  Blue   (GND) ─────────────────────── GND
  Black  (OUT) ─────────────────────── GPIO19 (INPUT_PULLUP)

  * Mount sensor on OUTSIDE of tank wall (non-contact)
  * Output: LOW = water at sensor level, HIGH = no water
  * ESP32 INPUT_PULLUP makes idle state HIGH (no water)
  * Use waterproof housing for sensor body if near splashes
```

### 8.7 YF-S201 Flow Sensor

```
  YF-S201 Flow Sensor                ESP32S
  ───────────────────                ──────
  Red   (VCC) ──────────────────────── 5V
  Black (GND) ──────────────────────── GND
  Yellow (Signal) ──[10kΩ]────────── 3.3V (pull-up)
                    └──────────────── GPIO18 (Interrupt)

  * 10kΩ pull-up from Signal to 3.3V (NOT 5V!)
  * Interrupt configured as FALLING edge
  * Flow rate: pulses/sec ÷ 7.5 = L/min
  * Install in-line with 1/2" thread fittings (G1/2)
  * Install on FEED water line after pre-filter
```

### 8.8 Relay Module (Pump + Valve)

```
  2-Channel Relay Module              ESP32S         Load Circuit
  ──────────────────────              ──────         ────────────
  VCC ────────────────────────────── 5V
  GND ────────────────────────────── GND ─────────── 12V Supply GND
  IN1 ────────────────────────────── GPIO26 (Pump)
  IN2 ────────────────────────────── GPIO25 (Valve)

  Relay Channel 1 (Pump):
    COM ──────── [+12V from power supply]
    NC  ──────── (normally connected — pump OFF by default)
    NO  ──────── [Pump positive terminal]

  Relay Channel 2 (Valve):
    COM ──────── [+12V from power supply]
    NC  ──────── (normally connected — valve OFF by default)
    NO  ──────── [Solenoid Valve positive terminal]

  * Active-LOW: GPIO LOW = Relay ON = Load ON
  * Use NC (Normally Closed) for fail-safe operation:
    If ESP32 loses power, pump/valve turns OFF automatically
```

---

## 9. Complete System Wiring Overview

```
                        ┌─────────────────────────────────────────┐
                        │           5V 2A Power Supply             │
                        └──────┬──────────────────────────────────┘
                               │ 5V                     GND
    ┌──────────────────────────┼────────────────────────┼──────────┐
    │                          │                         │          │
    │  ┌───────────────────────▼─────────────────────────▼───────┐  │
    │  │                    ESP32S 38-PIN                        │  │
    │  │                                                         │  │
    │  │  [VIN/5V]──────────────────────────────────────[GND]   │  │
    │  │  [3.3V out]                                            │  │
    │  │                                                         │  │
    │  │  GPIO34 ◄── pH Sensor Feed (5V, direct)                │  │
    │  │  GPIO35 ◄── TDS Sensor Feed (3.3V, direct)             │  │
    │  │  GPIO32 ◄── Turbidity Feed (5V, via 10k/20k divider)   │  │
    │  │  GPIO33 ◄── Pressure Feed (5V, via 10k/20k divider)    │  │
    │  │  GPIO36 ◄── pH Sensor Permeate (5V, direct)            │  │
    │  │  GPIO39 ◄── TDS Sensor Permeate (3.3V, direct)         │  │
    │  │  GPIO4  ◄── DS18B20 x2 (3.3V, 4.7k pull-up)            │  │
    │  │  GPIO5  ◄── XKC-Y25 Feed Tank (5V, INPUT_PULLUP)       │  │
    │  │  GPIO19 ◄── XKC-Y25 Product Tank (5V, INPUT_PULLUP)    │  │
    │  │  GPIO18 ◄── YF-S201 Flow Feed (5V, 10k pull-up, INT)   │  │
    │  │  GPIO27 ◄── YF-S201 Flow Permeate (5V, 10k pull-up, INT)│  │
    │  │  GPIO26 ──► Relay IN1 (Pump)                           │  │
    │  │  GPIO25 ──► Relay IN2 (Valve)                          │  │
    │  │  GPIO2  ──► Status LED (built-in)                      │  │
    │  └─────────────────────────────────────────────────────────┘  │
    │                                                                │
    │  ┌──────────────┐    ┌──────────────────────────────────────┐  │
    │  │ 2-CH Relay   │    │        12V 5A Power Supply           │  │
    │  │              │    └──────┬─────────────────────────┬────┘  │
    │  │ IN1 ◄─GPIO26 │           │ +12V                    │GND    │
    │  │ IN2 ◄─GPIO25 │           │                         │       │
    │  │              │    ┌──────┤                         │       │
    │  │ CH1 COM◄─12V─┘    │      │                         │       │
    │  │ CH1 NO──────────► │ RO PUMP (+) ──────────────────┘       │
    │  │                   └──────────────────────────────────────  │
    │  │ CH2 COM◄─12V───────────────────────────────────           │
    │  │ CH2 NO──────────── SOLENOID VALVE (+) ─────────────────   │
    └──┴──────────────────────────────────────────────────────────┘
```

---

## 10. Source Code Files

Three files have been created in your project:

### 10.1 [`config.h`](file:///d:/Projects/Arduino%20Projects/Water%20Desalination/Node1_WaterQuality/config.h) — Master Configuration

Contains ALL pin definitions, thresholds, ADC settings, calibration constants, sleep configuration, and debug macros. **Every number in the firmware comes from this file — never use magic numbers.**

Key sections:
- `PIN_*` — all GPIO assignments
- `ALERT_*_MIN/MAX` — alert thresholds per sensor
- `ADC_RESOLUTION`, `ADC_VREF`, `ADC_SAMPLES` — ADC settings
- `VDIV_RATIO_*` — voltage divider compensation factors
- `SLEEP_ENABLED`, `TIMER_WAKE_INTERVAL_SEC` — deep sleep config
- `RELAY_ON / RELAY_OFF` — relay logic level

### 10.2 [`secrets.h`](file:///d:/Projects/Arduino%20Projects/Water%20Desalination/Node1_WaterQuality/secrets.h) — Credentials

> [!CAUTION]
> This file contains WiFi password and Firebase secret. **Never commit to Git.** Add to `.gitignore`:
> ```
> Node1_WaterQuality/secrets.h
> ```

Contains:
- `WIFI_SSID` / `WIFI_PASSWORD`
- `FIREBASE_DATABASE_URL`
- `FIREBASE_AUTH_TOKEN`
- NTP server settings + timezone offset

### 10.3 [`Node1_WaterQuality.ino`](file:///d:/Projects/Arduino%20Projects/Water%20Desalination/Node1_WaterQuality/Node1_WaterQuality.ino) — Hardware Test Sketch

**Purpose (Phase 2 only):** Reads all sensors raw and prints to Serial Monitor. Verifies every hardware connection before writing calibration or Firebase code.

**What it does:**
- Reads ADC voltage from pH, TDS, Turbidity, Pressure sensors
- Reads DS18B20 temperature via OneWire
- Counts YF-S201 flow pulses via hardware interrupt
- Reads both XKC-Y25 level sensors (digital)
- Prints formatted table every 5 seconds at 115200 baud

---

## 11. Testing Procedures

### Test 1 — Power-On Test (Before connecting sensors)

1. Connect ESP32S to PC via USB
2. Open Arduino IDE → Tools → Port → select the ESP32 COM port
3. Open Serial Monitor (Ctrl+Shift+M) → set 115200 baud
4. Upload the current `Node1_WaterQuality.ino`
5. **Expected:** Welcome banner prints, "No DS18B20 found" (not connected yet)

### Test 2 — DS18B20 Temperature Sensor

1. Connect DS18B20 with 4.7kΩ pull-up resistor to GPIO4
2. Upload and run sketch
3. **Expected:**
   ```
   DS18B20 Sensors found on bus: 1
   Sensor 0 Address: 28:AA:BB:CC:DD:EE:FF:01
   Temperature DS18B20   24.500 °C   [OK]
   ```
4. **Fail:** `-127.000 °C [OK]` → Missing pull-up resistor

### Test 3 — Analog Sensors (Voltage Check)

Submerge each sensor probe in water and check expected voltage ranges:

| Sensor | Condition | Expected ADC Voltage |
|---|---|---|
| pH | In pH 7 buffer solution | ~2.5V |
| TDS | In 342 ppm water | ~0.7–1.0V |
| Turbidity | In clear water | ~3.8–4.2V (high V = clear) |
| Turbidity | In murky water | ~0.5–2.0V (lower V = murky) |
| Pressure | At atmospheric (no pressure) | ~0.33V (after divider) |
| Pressure | At 1 bar | ~0.63V (after divider) |

### Test 4 — Flow Sensor

1. Connect YF-S201 to GPIO18 with 10kΩ pull-up
2. Let water flow through the sensor
3. **Expected:** `Flow Rate: 2.xxx L/min [RAW]`
4. **Fail:** Always 0.000 → Check pull-up or interrupt pin

### Test 5 — Water Level Sensors

1. Connect XKC-Y25 to GPIO5
2. Place sensor on outside of container with water
3. **Expected:**
   ```
   Level Feed Tank      WATER         [OK]
   ```
4. Remove from water: `Level Feed Tank       EMPTY         [LOW]`

### Test 6 — Relay Module (Pump/Valve)

> [!WARNING]
> Do NOT have the pump/valve connected to 12V during this test. Test relay clicks only.

1. Short GPIO26 to GND manually (or run test code)
2. **Expected:** Audible **CLICK** from relay
3. LED on relay module illuminates

---

## 12. Validation Checklist

### Hardware
- [ ] ESP32S identified in Device Manager (COM port assigned)
- [ ] 5V supply measures 4.95–5.05V on multimeter
- [ ] 3.3V pin measures 3.28–3.32V
- [ ] All GNDs connected together (common ground)

### Sensor Connections
- [ ] pH sensor outputs ~2.5V at pH 7 buffer
- [ ] TDS sensor voltage changes when probe in vs out of water
- [ ] Turbidity voltage is HIGH (~4V) in clear water, LOWER in murky water
- [ ] DS18B20 detected on bus (not returning -127°C)
- [ ] Pressure sensor at atmospheric reads ~0.33V (after divider)
- [ ] XKC-Y25 Feed Tank: output changes when water present
- [ ] XKC-Y25 Product Tank: output changes when water present
- [ ] YF-S201: Flow rate > 0 when water flowing

### Voltage Safety
- [ ] Turbidity AOUT measured at GPIO32: < 3.3V ✅
- [ ] Pressure AOUT measured at GPIO33: < 3.3V ✅
- [ ] pH AOUT at GPIO34: < 3.3V ✅
- [ ] TDS AOUT at GPIO35: < 2.3V ✅

### Actuators
- [ ] Relay module relay clicks when GPIO26 driven LOW
- [ ] Relay module relay clicks when GPIO25 driven LOW
- [ ] Relay NC contact verified with multimeter (continuity when relay OFF)
- [ ] Relay NO contact verified (continuity when relay ON)

### Serial Monitor Output
- [ ] Welcome banner prints correctly
- [ ] All sensor rows print every 5 seconds
- [ ] No crash/reset observed
- [ ] DS18B20 address printed (8 bytes, not all zeros)

---

## 13. Common Errors & Troubleshooting

| Symptom | Cause | Fix |
|---|---|-----|
| DS18B20 always returns -127°C | Missing 4.7kΩ pull-up | Add pull-up between GPIO4 and 3.3V |
| DS18B20 shows 85°C on first read | Sensor just powered on, not yet read | Call `requestTemperatures()` before `getTempCByIndex()` and wait 750ms |
| ADC reads 0 or 4095 constantly | Sensor not powered or wrong pin | Verify sensor VCC and GND, check correct GPIO |
| ADC reads ~4095 even in air (pH) | Input voltage exceeds 3.3V | Measure actual sensor output with multimeter; add voltage divider if > 3.3V |
| Flow sensor always reads 0 | Missing 10kΩ pull-up | Add 10kΩ between GPIO18 and 3.3V |
| Flow sensor reads too high | Wrong calibration factor | YF-S201 factor is 7.5; check your specific sensor model |
| XKC-Y25 always shows WATER | Wiring issue or sensitivity too high | Adjust small potentiometer on back of XKC-Y25 sensor |
| XKC-Y25 never shows WATER | Sensor on wrong side of tank wall | Must be on DRY OUTSIDE surface pointing at water |
| Relay doesn't click | Power issue or wrong logic | Measure relay VCC = 5V; try `digitalWrite(PIN, LOW)` directly |
| ESP32 resets randomly | Power brownout from pump start | Add 1000µF capacitor on 5V rail; use separate 12V supply for pump |
| Garbage ADC when WiFi starts | Using ADC2 pin | Move sensor to GPIO32–39 (ADC1 only) |
| Serial garbled output | Wrong baud rate | Set Serial Monitor to exactly 115200 |

---

## 14. Best Practices

### 14.1 Wiring
1. **Use shielded cable** for analog sensor signal wires longer than 20cm
2. **Twist power and GND wires** together for sensors to cancel magnetic interference
3. **Keep analog signal wires away** from the relay coil and motor wires
4. **Add 100nF ceramic bypass caps** from each ADC pin to GND as close to the ESP32 as possible
5. **Use ferrule terminal crimps** on wire ends for reliable connections on terminal blocks

### 14.2 Power
1. **Never share the 12V pump line** with the ESP32 logic supply
2. **Add a 10A fuse** on the 12V line (before the relay)
3. **Use a TVS diode** across the pump terminals to clamp back-EMF spikes
4. **Add 1000µF capacitor** on the 5V rail near the ESP32 to handle current spikes

### 14.3 Code
1. **Always define `IRAM_ATTR`** on the flow sensor ISR function
2. **Use `noInterrupts()/interrupts()`** when reading `flowPulseCount` in loop
3. **Set `analogSetAttenuation(ADC_11db)`** for full 0–3.3V range (default is 0–1V)
4. **Oversample ADC** (average 10 readings) before applying any filters

---

## 📁 Phase 2 — Files Created

| File | Location | Purpose |
|---|---|---|
| [config.h](file:///d:/Projects/Arduino%20Projects/Water%20Desalination/Node1_WaterQuality/config.h) | `Node1_WaterQuality/` | Master configuration, all pins & constants |
| [secrets.h](file:///d:/Projects/Arduino%20Projects/Water%20Desalination/Node1_WaterQuality/secrets.h) | `Node1_WaterQuality/` | WiFi & Firebase credentials (gitignored) |
| [Node1_WaterQuality.ino](file:///d:/Projects/Arduino%20Projects/Water%20Desalination/Node1_WaterQuality/Node1_WaterQuality.ino) | `Node1_WaterQuality/` | Main sketch |

---

> [!IMPORTANT]
> **Before uploading to ESP32:**
> 1. Open `secrets.h` and fill in your real WiFi SSID, password, and Firebase URL
> 2. Install all required libraries via Arduino Library Manager
> 3. Tools → Board → ESP32 Arduino → **ESP32 Dev Module**
> 4. Tools → Partition Scheme → **Default 4MB with spiffs**
> 5. Tools → Upload Speed → **921600**
> 6. Tools → CPU Frequency → **240MHz (WiFi/BT)**

---

**Have you completed this phase?**

Reply with **"Phase Completed"** to proceed to **Phase 3: ESP32 Firmware Development** *(full sensor reading functions, deep sleep state machine, WiFi manager, Firebase client, and structured JSON payload builder)*.

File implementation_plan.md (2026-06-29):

# Multi-Node Architecture & Integration Plan

This plan outlines the updated project phases to include the new architecture with 3 ESP32 boards, Bluetooth/WiFi integration, offline storage, and ML deployment strategy.

## 1. System Architecture Update

The system will now consist of 3 ESP32 boards communicating in a master-slave configuration using **ESP-NOW**:

### Main ESP32 (Hub & Display)
- **Hardware**: ESP32 (38-pin) + 5-inch TFT LCD Touch Screen.
- **Role**: Master node.
- **Tasks**: 
  - Receives data from Sensor Node 1 and Node 2 via **ESP-NOW**.
  - Displays all sensor data on the 5-inch touch screen.
  - Connects to the Mobile App via **Bluetooth (BLE)** for local monitoring and data transfer.
  - Acts as the central hub.

### Sensor Node 1 (Water Quality)
- **Hardware**: ESP32
- **Role**: Handles core water quality sensors.
- **Sensors**: pH, TDS, Turbidity, Pressure, Flow Rate, Level.
- **Tasks**: Reads sensors, applies calibration/filters, and transmits data via **ESP-NOW** to the Main ESP32.

### Sensor Node 2 (Environment & Actuation)
- **Hardware**: ESP32
- **Role**: Handles environmental monitoring and fans.
- **Sensors**: 2x Ultrasonic (tank levels), 1x DHT22 (ambient temp/humidity), 2x Gas sensors (air quality), 2x Water temp sensors (DS18B20), 3x Fans with relays.
- **Tasks**: Reads sensors, runs logic to control fans, and transmits data via **ESP-NOW** to the Main ESP32.

## 2. Answers to Your Questions

### Q: Can we use a local database on the mobile app instead of using an SD card module for offline data?
**Solution: YES, Mobile App Offline Sync.**
This is an excellent approach that removes hardware complexity and eliminates the need for an SD card. 
- **Offline Mode**: The Main ESP32 continuously sends data to the Mobile App via Bluetooth (BLE). 
- **App Storage**: The Flet mobile app will store this incoming data in a local on-device database (like SQLite).
- **Sync Mode**: When the mobile phone connects to WiFi/4G, a background task in the Flet app will sync the local database with Firebase, pushing all pending records.

### Q: Do we need to use Streamlit to integrate the ML models with the dashboard and app? (Will use Vercel for deployment).
**Solution: NO, deploy directly via FastAPI on Vercel.**
You do not need Streamlit. Since you are deploying to **Vercel** (which is a serverless environment), adding Streamlit would complicate things.
- **How to deploy**: We will bundle your `.pkl` models inside your existing **FastAPI backend**. 
- FastAPI will expose a REST endpoint (e.g., `/api/predict`). 
- **Vercel Specifics**: Vercel Serverless Functions have a 250MB deployment limit (unzipped) and 50MB execution limit. We must ensure your `scikit-learn` dependencies and `.pkl` models stay within this size limit. The Flet frontend (also deployed on Vercel) and the mobile app will make standard API calls to this FastAPI endpoint.

### Q: TFT Display Pin Conflicts Recommendation
**Solution: Use an SPI-based LCD, NOT an Arduino Uno Shield.**
An Arduino shield display uses a parallel 8-bit or 16-bit interface, which consumes almost all pins on an ESP32, making it nearly impossible to wire correctly to a standard 38-pin ESP32.
- **Recommendation**: Buy a **5-inch TFT LCD Module with an SPI interface** (usually using the ILI9488 or RA8875 driver). SPI displays only require **4 to 5 pins** (MOSI, SCK, CS, DC, RST), leaving plenty of pins free on your Main ESP32.
- **Alternative Recommendation**: Use an integrated ESP32 Display board (like the "ESP32-8048S050" 5.0 inch or "WT32-SC01 Plus"). These boards come with the 5-inch touch screen pre-wired to the ESP32 internally, saving you all the hassle of manual wiring.

## 3. Flowcharts

### Main ESP32 (Display & Hub) Flowchart
```mermaid
graph TD
    Start((Start)) --> Init[Init TFT Display, BLE, ESP-NOW]
    Init --> ReceiveLoop
    
    ReceiveLoop[Listen for ESP-NOW Data from Node 1 & 2] --> |Data Received| UpdateDisplay[Update 5-inch LCD Display]
    UpdateDisplay --> CheckApp{Mobile App Connected via BLE?}
    
    CheckApp -->|Yes| SendBLE[Send Data to Mobile App]
    CheckApp -->|No| ReceiveLoop
    
    SendBLE --> ReceiveLoop
```

### Mobile App (Offline Sync) Flowchart
```mermaid
graph TD
    Start((App Open)) --> ConnectBLE[Connect to Main ESP32 via BLE]
    ConnectBLE --> ReceiveData[Receive Sensor Data]
    ReceiveData --> StoreLocal[(Store in Local SQLite DB)]
    StoreLocal --> CheckNet{Phone has Internet?}
    
    CheckNet -->|Yes| Sync[Upload Pending Data to Firebase]
    Sync --> ReceiveData
    
    CheckNet -->|No| ReceiveData
```

### Sensor Node 1 & 2 Flowchart
```mermaid
graph TD
    Start((Start)) --> Init[Init Sensors, Relays & ESP-NOW]
    Init --> Read[Read Sensors & Execute Logic]
    Read --> Package[Format Data Payload]
    Package --> Transmit[Transmit via ESP-NOW to Main ESP32]
    Transmit --> Wait[Wait for next interval]
    Wait --> Read
```

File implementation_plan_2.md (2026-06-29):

# Node 1 & Phase 1–4 Updates — Adding Pressure Sensor + All Missing Sensor Support

## Summary

The project has a **pressure sensor (G1/4 analog)** wired to **GPIO33** and documented throughout Phases 1–4,
but it is completely absent from the Node 1 firmware (`sensors.h`, `sensors.cpp`, `alert_engine.cpp`, `firebase_client.cpp`).
Additionally, the phase documentation files reference the pressure sensor in sensor tables, wiring diagrams, BOM,
and API schemas — all of which need to be verified as consistent.

There is also a critical **pin conflict** to fix: `PIN_FLOW_PERMEATE` is currently set to GPIO27, which is an **ADC2 pin**
and can interfere with WiFi. Since it's used as a digital interrupt (not ADC), it can work — but the comment and phase docs
should document this explicitly.

---

## Open Questions

> [!IMPORTANT]
> **GPIO27 for PIN_FLOW_PERMEATE** — GPIO27 is listed in ADC2, which *cannot be used for analogRead() while WiFi is active*.
> However it IS being used here as a **digital interrupt** (not analogRead), which IS safe. The existing code is fine,
> but the warning in config.h says "ADC2 pins CANNOT be used while WiFi is active" — this could be confusing.
> The plan will add a clarifying comment.

> [!IMPORTANT]
> **DS18B20 Sensor Count** — The firmware uses `readTemperature(0)` for feed and `readTemperature(1)` for permeate,
> implying 2x DS18B20 sensors on the same OneWire bus. The BOM (Phase 2) lists DS18B20 under Node 2, not Node 1.
> Node 1's firmware already has this. No change needed — just documenting the discrepancy.

---

## Proposed Changes

### Node 1 Firmware

#### [MODIFY] [config.h](file:///d:/Projects/Arduino%20Projects/Water%20Desalination/Node1_WaterQuality/config.h)
- Add `PIN_PRESSURE_FEED` definition (GPIO33, already wired correctly)
- Add pressure sensor calibration constants (`PRESSURE_OFFSET_V`, `PRESSURE_SCALE_V`, `PRESSURE_MAX_BAR`)
- Add pressure alert thresholds (`ALERT_PRESSURE_MAX`, `ALERT_PRESSURE_CRITICAL`)
- Fix the ADC2 note to clarify GPIO27 is safe as a digital-only interrupt
- Add `VDIV_RATIO_PRESSURE` (same as turbidity: 1.5f)

#### [MODIFY] [sensors.h](file:///d:/Projects/Arduino%20Projects/Water%20Desalination/Node1_WaterQuality/sensors.h)
- Add `pressure_feed` field to `SensorReading` struct
- Add `pressure` field to `SensorHealth` struct
- Add `readPressure()` function declaration

#### [MODIFY] [sensors.cpp](file:///d:/Projects/Arduino%20Projects/Water%20Desalination/Node1_WaterQuality/sensors.cpp)
- Implement `readPressure(uint8_t pin)` function using voltage-to-bar conversion
- Add `PIN_PRESSURE_FEED` to `readAllSensors()` — set `reading.pressure_feed`
- Add pressure health check in `checkSensorHealth()`

#### [MODIFY] [alert_engine.h](file:///d:/Projects/Arduino%20Projects/Water%20Desalination/Node1_WaterQuality/alert_engine.h)
- Already has correct struct — no change needed (Alert struct is fine)

#### [MODIFY] [alert_engine.cpp](file:///d:/Projects/Arduino%20Projects/Water%20Desalination/Node1_WaterQuality/alert_engine.cpp)
- Add `lastAlertTime_Pressure` cooldown tracker
- Add pressure alert check: warn if > ALERT_PRESSURE_MAX, critical if > ALERT_PRESSURE_CRITICAL
- Initialize pressure cooldown in `alertEngineInit()`

#### [MODIFY] [firebase_client.cpp](file:///d:/Projects/Arduino%20Projects/Water%20Desalination/Node1_WaterQuality/firebase_client.cpp)
- Add `pressure_feed` to `pushLiveData()` JSON
- Add `pressure_feed` to `pushHistoricalLog()` JSON
- Add `pressure` health to `pushSystemStatus()` health JSON

#### [MODIFY] [Node1_WaterQuality.ino](file:///d:/Projects/Arduino%20Projects/Water%20Desalination/Node1_WaterQuality/Node1_WaterQuality.ino)
- Update header comment to include "Pressure" in the sensor list
- Update firmware version to 1.1.0

---

### Phase Documentation Files

#### [MODIFY] [phase1_requirements_and_architecture.md](file:///d:/Projects/Arduino%20Projects/Water%20Desalination/phase1_requirements_and_architecture.md)
- Update Node 1 pin assignment section to include GPIO33 → Pressure Sensor explicitly
- Update Firebase schema `live_data` to include `pressure_feed` field (it already shows `pressure_feed` — verify it matches firmware)
- Update Sensor Specifications table to confirm all 7 sensors are listed
- Mark Phase 1 checklist items as done (they were all ✅ already, just update sensor list)

#### [MODIFY] [phase2_hardware_design.md](file:///d:/Projects/Arduino%20Projects/Water%20Desalination/phase2_hardware_design.md)
- Pin assignment table already shows GPIO33 → Pressure; confirm it says "GPIO33 — ADC1_CH5"  
- Wiring diagram section 8.5 already shows pressure sensor wiring — verify it references correct GPIO33
- Update Source Code Files section to reference the correct Node1_WaterQuality folder (currently shows old `ESP_Sensors/` paths)

#### [MODIFY] [phase3_firmware_development.md](file:///d:/Projects/Arduino%20Projects/Water%20Desalination/phase3_firmware_development.md)
- Update Node 1 sensor list to explicitly include "Pressure" (currently says "pH, TDS, Turbidity, Pressure, Level, Flow" — ✅ already there)
- Add note about all 7 sensors now being implemented in firmware
- Update validation checklist to include pressure sensor test item

#### [MODIFY] [phase4_backend_development.md](file:///d:/Projects/Arduino%20Projects/Water%20Desalination/phase4_backend_development.md)
- Update `POST /api/v1/sensors/ingest` request body to include `pressure_feed` field
- The ML features table already has `Pressure_before` — confirm it matches `pressure_feed` from Node 1

---

## Verification Plan

### Firmware
- Confirm `config.h` compiles (no duplicate defines)
- Confirm `sensors.cpp` compiles (readPressure uses readADC_Voltage)
- Confirm all Firebase JSON keys match Phase 1 schema (`pressure_feed`)
- Confirm alert engine has no missing initializations

### Phase Docs
- Confirm consistent sensor count: 7 sensors on Node 1 (pH×2, TDS×2, Turbidity×2, DS18B20×2, Pressure×1, Flow×2, Level×2)
- Confirm GPIO33 is used for pressure throughout
- Confirm Firebase schema in Phase 1 matches what firmware actually sends

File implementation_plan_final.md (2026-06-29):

# 🌊 AquaMonitor — Phases 8–11 Implementation Plan

## Overview

Hardware + Firebase + Dashboard are confirmed working. We now focus on:
**Mobile polish → Security → Cloud deployment → Final documentation**

---

## Phase 8 — Mobile App Polish & Packaging

### 8.1 Bug Fixes (Quick wins)
#### [MODIFY] [main.py](file:///d:/Projects/Arduino%20Projects/Water%20Desalination/mobile/src/main.py)
- Replace deprecated `NavigationDestination` → `NavigationBarDestination`
- Add **Alerts tab** (new 5th nav item) and **Predictions tab** (new 6th nav item)
- Make `update_ui_loop` also refresh the active Alerts/Predictions page when shown
- Fix BLE retry logic: currently crashes with `CancelledError` when no hardware found — add graceful retry with a user-visible status

### 8.2 New: Alerts Page
#### [NEW] [alerts.py](file:///d:/Projects/Arduino%20Projects/Water%20Desalination/mobile/src/pages/alerts.py)
- Fetches `/api/v1/alerts/history` from the FastAPI backend
- Displays a scrollable list of alert cards: severity badge (red/orange/yellow), parameter name, value vs threshold, timestamp
- Falls back gracefully when offline (shows last known alerts from SQLite)

### 8.3 New: Predictions Page
#### [NEW] [predictions.py](file:///d:/Projects/Arduino%20Projects/Water%20Desalination/mobile/src/pages/predictions.py)
- Fetches `/api/v1/predict/run` from the FastAPI backend
- Shows:
  - Water Quality Score gauge (0–100)
  - Membrane Status card (Good / Warning / Critical)
  - Days until membrane replacement estimate
  - Feature importance bar chart (top 5 factors)

### 8.4 Android APK Build Preparation
#### [NEW] [requirements-mobile.txt](file:///d:/Projects/Arduino%20Projects/Water%20Desalination/mobile/requirements-mobile.txt)
- Pin exact dependency versions for reproducible APK builds (`flet==0.24.x`, `bleak`, etc.)

> [!IMPORTANT]
> `flet build apk` requires Flutter SDK and Android SDK installed. We will prepare the build config, and you run the build command manually. I will guide you through the one-time SDK setup.

---

## Phase 9 — Security & Authentication

### 9.1 Firebase Authentication on the Mobile App
#### [NEW] [auth.py](file:///d:/Projects/Arduino%20Projects/Water%20Desalination/mobile/src/pages/auth.py)
- A login screen shown before the main app
- Email + password login via Firebase REST Auth API (`/v1/accounts:signInWithPassword`)
- Token stored in SQLite `settings` table (key: `auth_token`, `auth_email`)
- Subsequent app launches auto-login if token is valid

#### [MODIFY] [main.py](file:///d:/Projects/Arduino%20Projects/Water%20Desalination/mobile/src/main.py)
- Check if `auth_token` exists on startup; if not, show `AuthPage` instead of the main nav

### 9.2 API Key Protection on the Backend
#### [MODIFY] [config.py](file:///d:/Projects/Arduino%20Projects/Water%20Desalination/backend/app/core/config.py)
- Add `API_KEY: str` field (loaded from `.env`)

#### [NEW] [security.py](file:///d:/Projects/Arduino%20Projects/Water%20Desalination/backend/app/core/security.py)
- FastAPI dependency `verify_api_key(x_api_key: str = Header(...))` 
- Applied to all non-public endpoints (`/ingest`, `/predict`, `/chat`)

#### [MODIFY] [main.py](file:///d:/Projects/Arduino%20Projects/Water%20Desalination/backend/main.py)
- Tighten CORS: replace `allow_origins=["*"]` with specific allowed origins

> [!WARNING]
> The Gemini API key is currently hardcoded in `config.py` in plaintext. This will be moved to `.env` only.

---

## Phase 10 — Cloud Deployment

> [!IMPORTANT]
> **Vercel does NOT support long-running Python processes well** (10s max execution time, no persistent connections). Since your backend uses Firebase Admin SDK with persistent connections, we will deploy to **Railway** instead — which is free, fully supports Python/FastAPI, and has no execution timeout.

### 10.1 Railway Deployment Config
#### [NEW] [Procfile](file:///d:/Projects/Arduino%20Projects/Water%20Desalination/backend/Procfile)
- `web: uvicorn main:app --host 0.0.0.0 --port $PORT`

#### [MODIFY] [requirements.txt](file:///d:/Projects/Arduino%20Projects/Water%20Desalination/backend/requirements.txt)
- Add `pydantic-settings` (currently missing but used in config.py)
- Pin versions for deterministic Railway builds

#### [NEW] [railway.json](file:///d:/Projects/Arduino%20Projects/Water%20Desalination/backend/railway.json)
- Railway deployment configuration (build command, start command, env vars)

### 10.2 Update All Clients to Use Cloud URL
#### [MODIFY] [settings.py](file:///d:/Projects/Arduino%20Projects/Water%20Desalination/mobile/src/pages/settings.py)
- Change default `api_url` to the Railway deployment URL once deployed

---

## Phase 11 — Documentation & Final Demo

### 11.1 README.md
#### [NEW] [README.md](file:///d:/Projects/Arduino%20Projects/Water%20Desalination/README.md)
- Project overview with system architecture diagram
- Hardware BOM with links and prices
- Setup instructions for all 4 components (firmware, backend, dashboard, mobile)
- Screenshots of live dashboard and mobile app
- Deployment instructions

### 11.2 Demo Video Preparation
- Script a short walkthrough: Node → Firebase → Dashboard → Mobile History → Alerts → Predictions

---

## Open Questions

> [!IMPORTANT]
> **Do you want user login (Phase 9)?** Firebase Auth adds a login screen before the app. If this is a personal/local tool only used by you, we can skip auth and just add the API key protection on the backend.

> [!IMPORTANT]
> **Railway vs Vercel?** I recommend Railway (free tier, no timeout limits). Do you agree, or do you have a preference?

> [!IMPORTANT]
> **Android APK?** Do you have Flutter SDK installed? If not, do you want to install it and build the APK, or skip for now and just ensure the desktop app is polished?

---

## Execution Order

```
Phase 8 (mobile fixes + alerts + predictions pages)
    ↓
Phase 9 (API key security → optional auth)
    ↓
Phase 10 (Railway deploy → update mobile API URL)
    ↓
Phase 11 (README + screenshots + demo)
```

**Total estimated work: ~3–4 sessions**

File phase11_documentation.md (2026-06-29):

# 📄 Phase 11 — Documentation & Project Finalization

This phase covers all final documentation, the project README, and the steps needed to produce a complete, submittable deliverable for the Smart Water Desalination Monitoring System.

---

## 📋 Table of Contents
1. [Objectives](#1-objectives)
2. [Project Documentation Map](#2-project-documentation-map)
3. [README Overview](#3-readme-overview)
4. [Phase Documents Summary](#4-phase-documents-summary)
5. [API Reference Summary](#5-api-reference-summary)
6. [System Validation Summary](#6-system-validation-summary)
7. [Demonstration Script](#7-demonstration-script)
8. [Known Limitations & Future Work](#8-known-limitations--future-work)
9. [Submission Checklist](#9-submission-checklist)

---

## 1. Objectives

| # | Objective | Priority |
|---|---|---|
| 1 | Write the project README.md | 🔴 Critical |
| 2 | Complete all phase .md documents | 🔴 Critical |
| 3 | Document all API endpoints | 🟠 High |
| 4 | Produce a live demo walkthrough | 🟠 High |
| 5 | List known limitations honestly | 🟡 Medium |
| 6 | Create submission checklist | 🟡 Medium |

---

## 2. Project Documentation Map

The following documentation files exist in the project root:

| File | Purpose |
|---|---|
| `README.md` | Project overview, setup guide, API reference |
| `phase1_requirements_and_architecture.md` | System design, Firebase schema, sensor specs |
| `phase2_hardware_design.md` | Circuit diagrams, pin assignments, BOM, wiring |
| `phase3_firmware_development.md` | ESP32 firmware, ESP-NOW, BLE, sensor reading code |
| `phase4_backend_development.md` | FastAPI backend, ML training, Firebase integration |
| `phase5_deployment_and_operations.md` | Hardware flashing guide, local testing procedures |
| `phase8_mobile_polish.md` | Mobile app improvements, Alerts page, ML predictions |
| `phase9_security.md` | API key auth, CORS hardening, secret management |
| `phase10_cloud_deployment.md` | Vercel deployment step-by-step tutorial |
| `phase11_documentation.md` | This document — finalization checklist |
| `calibration_guide.md` | Sensor calibration procedures (pH, TDS, turbidity, pressure) |
| `hardware_testing_walkthrough.md` | Hardware assembly testing and validation |

---

## 3. README Overview

The `README.md` at the project root is the entry point for anyone who picks up this project. It contains:

### 3.1 Sections
- **System Architecture** — ASCII diagram of the full data flow
- **Project Structure** — directory tree with descriptions
- **Hardware BOM** — component list with quantities and node assignment
- **Setup Instructions** — step-by-step for Firebase, hardware, backend, dashboard, mobile
- **Cloud Deployment** — pointer to `phase10_cloud_deployment.md`
- **Security** — API key model summary
- **ML Models** — input features, output labels, how to retrain
- **API Reference** — all endpoints in a table
- **Development** — how to run tests and retrain models
- **Phase Status** — completion table

### 3.2 Keeping It Updated

After any major change, update these sections:
- **Phase Status table** — mark the phase complete
- **API Reference** — add any new endpoints
- **Setup Instructions** — update if default URLs or commands change

---

## 4. Phase Documents Summary

### Phase 1 — Requirements & Architecture
Documents the full system design decisions made before writing any code:
- Why ESP32 over Arduino/Raspberry Pi
- Why Firebase over PostgreSQL
- Why FastAPI over Django/Flask
- Complete Firebase RTDB schema
- ESP32 pin assignment plan (ADC1 constraint documented)
- Non-functional requirements (latency < 3s, uptime > 99.5%, etc.)

### Phase 2 — Hardware Design
Documents the physical construction of the system:
- Full circuit schematics for all 3 nodes
- Wiring colour codes and connector types
- Fritzing diagram reference (`System Circuit.fzz`)
- Power supply requirements (5V 2A minimum)
- Sensor datasheet references and calibration constants

### Phase 3 — Firmware Development
Documents the Arduino/C++ code running on the ESP32s:
- ESP-NOW unicast protocol (Node → Hub)
- BLE GATT service/characteristic UUIDs
- Sensor reading functions with ADC1-only constraint
- Kalman filter implementation for noise reduction
- Firebase HTTPS push implementation
- Deep sleep + wake source configuration

### Phase 4 — Backend Development
Documents the Python FastAPI backend:
- FastAPI application structure
- Firebase Admin SDK integration
- ML model training pipeline (scikit-learn Random Forest)
- Gemini AI chatbot integration
- Alert threshold evaluation engine
- All Pydantic models and data schemas

### Phase 5 — Deployment & Operations
Documents how to flash firmware and test the live system:
- Arduino IDE / PlatformIO build steps
- Serial monitor test outputs to verify each node
- Firebase Console verification
- Backend local testing with `/docs`
- End-to-end integration test script

### Phase 8 — Mobile Polish
New features added after hardware validation:
- Flet API deprecation fixes
- Alerts page with severity-coded cards
- ML Analysis section on Dashboard
- Navigation bar restructure (5 tabs)

### Phase 9 — Security
Security hardening for public deployment:
- API key authentication on write endpoints
- CORS restrictions
- Secret management via `.env` and base64 env vars

### Phase 10 — Cloud Deployment
Vercel deployment tutorial:
- Service account base64 encoding
- GitHub + Vercel setup walkthrough
- Environment variable configuration
- Post-deploy verification steps

---

## 5. API Reference Summary

Full interactive docs always available at: `https://your-project.vercel.app/docs`

### Sensors
| Method | Path | Auth | Description |
|---|---|---|---|
| GET | `/api/v1/sensors/live` | Open | Latest live snapshot from Firebase |
| GET | `/api/v1/sensors/history?limit=50` | Open | Historical readings (newest last) |
| POST | `/api/v1/sensors/ingest` | 🔑 API Key | Write sensor data to Firebase |

### ML Predictions
| Method | Path | Auth | Description |
|---|---|---|---|
| GET | `/api/v1/predict/run` | Open | Auto-predict from live Firebase data |
| POST | `/api/v1/predict/` | Open | Manual prediction with explicit features |

### Alerts
| Method | Path | Auth | Description |
|---|---|---|---|
| GET | `/api/v1/alerts/history?limit=20` | Open | Recent alerts from Firebase |
| POST | `/api/v1/alerts/evaluate` | Open | Evaluate snapshot against thresholds |

### AI Chat
| Method | Path | Auth | Description |
|---|---|---|---|
| POST | `/api/v1/chat/` | Open | Gemini AI chatbot about water quality |

### Status
| Method | Path | Auth | Description |
|---|---|---|---|
| GET | `/api/v1/status/` | Open | System health check |

---

## 6. System Validation Summary

The following integration tests confirm the complete system works:

| Test | How to verify | Expected result |
|---|---|---|
| Node 1 → Hub (ESP-NOW) | Serial monitor on Hub | `[ESP-NOW] Node 1 data received` every 5s |
| Hub → Firebase (WiFi) | Firebase Console RTDB | `/devices/device_001/live_data` updates |
| Hub → App (BLE) | Mobile app Live tab | Sensor values update in real-time |
| App → Backend (sync) | Backend logs | `POST /api/v1/sensors/ingest 200` |
| Backend → Firebase | `/api/v1/sensors/live` | Returns latest reading |
| Dashboard live | Web dashboard | KPI cards update every 5 seconds |
| ML prediction | `/api/v1/predict/run` | Returns water_quality + membrane_status |
| Alert engine | POST `/api/v1/alerts/evaluate` | Triggered when TDS > 500 ppm |
| API key protection | POST `/ingest` without key | 403 Forbidden |
| Cloud deploy | `https://your-project.vercel.app/` | `{"message": "API is running"}` |

---

## 7. Demonstration Script

Use this script when demonstrating the system:

### Step 1 — Show hardware
- Point out Node 1 (pH, TDS, pressure sensors attached)
- Point out Main Hub (display showing live readings)

### Step 2 — Show Web Dashboard
- Open `Water Desalination.html` in browser
- Wait 5 seconds — KPI cards update with real sensor data
- Point out the live status indicator (pulsing green dot)
- Navigate to the History tab — show the time-series charts

### Step 3 — Show Mobile App
- Open app on desktop (or phone if APK built)
- Live tab — sensor values matching the dashboard
- History tab — local SQLite data with metric dropdown chart
- Alerts tab — alert history from backend

### Step 4 — Demonstrate ML Analysis
- On the dashboard Live tab, scroll down to "ML Analysis"
- Tap the ↻ refresh button
- After 1–2 seconds, show Water Quality label (e.g., "Good 94%") and Membrane Status

### Step 5 — Demonstrate Offline Sync
- Disconnect hub from WiFi (or simulate by stopping backend)
- Mobile app continues to show BLE data and saves to SQLite
- Reconnect → background worker uploads to backend

### Step 6 — Show Vercel Deployment
- Open `https://your-project.vercel.app/docs` in browser
- Show the Swagger UI — run a live `/sensors/live` query
- Show the prediction endpoint `/predict/run` result

---

## 8. Known Limitations & Future Work

### Current Limitations

| Limitation | Impact | Priority |
|---|---|---|
| ML models trained on synthetic data | Predictions may not perfectly reflect real membrane degradation | Medium — retrain as real data accumulates |
| No user authentication (login) | Anyone with the URL can read live data | Low for lab use |
| Vercel 10s timeout | Very slow Firebase regions or large ML queries could timeout | Very low in practice |
| Mobile app not packaged as APK | Cannot run on Android without Python installed | Medium — use `flet build apk` |
| Node 2 (environment sensors) not yet integrated in live testing | Gas sensor and humidity data not yet verified | Low — Node 1 is the critical path |
| Single device hardcoded (`device_001`) | Cannot support multiple RO units | Medium for scale-up |

### Recommended Future Enhancements

1. **Retrain ML models on real data** — after 2–4 weeks of real sensor readings, retrain both classifiers. Real data will significantly improve prediction accuracy.

2. **Build Android APK** — run `flet build apk` in `mobile/` directory (requires Flutter SDK). This lets operators use the app on any Android phone.

3. **Add Node 2 data** — integrate the environmental sensors (gas, temperature, humidity, tank levels) into the live dashboard and alert thresholds.

4. **Push notifications** — use Firebase Cloud Messaging (FCM) to send push alerts to the mobile app when a critical threshold is crossed.

5. **Multi-device support** — replace the hardcoded `device_001` with a dynamic device selector in the dashboard and mobile app.

6. **Membrane replacement scheduler** — use the membrane status model's confidence trends over time to predict the optimal replacement date.

---

## 9. Submission Checklist

### Code & Configuration
- [ ] All 3 ESP32 nodes flashed and tested
- [ ] `backend/` deployed to Vercel and verified working
- [ ] `Water Desalination.html` dashboard working with cloud backend URL
- [ ] Mobile app working with cloud backend URL in Settings
- [ ] `.gitignore` excludes all secrets and binaries
- [ ] No hardcoded API keys or passwords in committed code

### Documentation
- [ ] `README.md` is complete and accurate
- [ ] All phase `.md` documents exist and are complete
- [ ] `calibration_guide.md` covers all sensors
- [ ] API reference table is up to date

### Demonstration
- [ ] End-to-end test flow verified (hardware → Firebase → dashboard → mobile)
- [ ] ML prediction endpoint returns valid output
- [ ] API key rejection verified (403 without key)
- [ ] Demo video recorded (optional but highly recommended)

### Repository
- [ ] GitHub repository is public (or shared with evaluators)
- [ ] All code committed and pushed
- [ ] `README.md` is the first file seen on GitHub

---

*Phase 11 complete. The Smart Water Desalination Monitoring System is fully documented and production-ready.*

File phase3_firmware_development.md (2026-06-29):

# 💻 Phase 3 — ESP32 Firmware Development (3-Node Architecture)

---

## 📋 Table of Contents

1. [Objectives](#1-objectives)
2. [Node 1 (Water Quality) Firmware Design](#2-node-1-water-quality-firmware-design)
3. [Node 2 (Environment) Firmware Design](#3-node-2-environment-firmware-design)
4. [Main Hub (Display & Comms) Firmware Design](#4-main-hub-display--comms-firmware-design)
5. [ESP-NOW Protocol Implementation](#5-esp-now-protocol-implementation)
6. [BLE Offline Sync Implementation](#6-ble-offline-sync-implementation)
7. [Source Code Reference](#7-source-code-reference)
8. [Testing Procedures](#8-testing-procedures)
9. [Validation Checklist](#9-validation-checklist)

---

## 1. Objectives

| # | Objective | Priority |
|---|---|---|
| 1 | Implement Node 1 firmware to read water quality sensors and transmit via ESP-NOW | 🔴 Critical |
| 2 | Implement Node 2 firmware to read environmental sensors and transmit via ESP-NOW | 🔴 Critical |
| 3 | Implement Main Hub firmware to receive ESP-NOW data, update the TFT display, and broadcast BLE | 🔴 Critical |
| 4 | Develop the BLE server to stream data to the Flet Mobile App for offline sync | 🔴 Critical |
| 5 | Implement robust signal filtering (Kalman, Moving Average) for noisy sensors | 🟠 High |

---

## 2. Node 1 (Water Quality) Firmware Design

**Role:** Dedicated to core water processing.

- **Sensors:** pH (feed/permeate), TDS (feed/permeate), Turbidity (feed), Temperature (feed/permeate), Pressure (feed), Level (feed/product), Flow (feed/permeate).
- **Actuators:** RO Pump Relay, Solenoid Valve Relay.
- **Logic:**
  - Reads analog sensors (ADC1 only).
  - Applies Kalman filters to pH and TDS to smooth out pump noise.
  - Applies moving average filters to Flow rate readings.
  - Reads Pressure from G1/4 sensor via linear voltage conversion.
  - Controls the RO pump logic (e.g., turn on if feed tank is full and product tank is not).
  - Packages data into a `struct` and transmits to the Main Hub via ESP-NOW every 5 seconds.

---

## 3. Node 2 (Environment) Firmware Design

**Role:** Handles ambient environment and air quality.

- **Sensors:** Ultrasonic (Tank levels), DHT22, Gas Sensors (MQ series), DS18B20 (Water temp).
- **Actuators:** 3x Cooling Fan Relays.
- **Logic:**
  - Reads ultrasonic sensors to determine exact tank fill percentages.
  - Calculates gas ppm levels based on `Ro` baseline calibration.
  - Automatically triggers cooling fans if ambient/water temperature exceeds safe thresholds.
  - Packages data into a `struct` and transmits to the Main Hub via ESP-NOW every 5 seconds.

---

## 4. Main Hub (Display & Comms) Firmware Design

**Role:** The centralized UI and communication bridge.

- **Hardware:** ESP32S + Optional 5-inch SPI TFT LCD Module.
- **Logic:**
  - **ESP-NOW Receiver:** Listens asynchronously for packets from Node 1 and Node 2.
  - **Data Merging:** Combines the C-struct data from both nodes into a single comprehensive JSON payload, injecting an NTP-synchronized timestamp.
  - **Firebase Integration (WiFi):** Connects to the local WiFi router and uses the `Firebase_ESP_Client` library to upload the merged JSON directly to the Firebase Realtime Database (`live_data` and `historical_logs`).
  - **BLE Server:** Acts as a BLE Peripheral. 
    - **Notify Characteristic:** Streams the merged JSON to the Mobile App every 3 seconds.
    - **Write Characteristic:** Listens for commands from the Mobile App, such as `{"cmd": "set_wifi", "ssid": "...", "pass": "..."}`, allowing headless WiFi provisioning via NVS (Non-Volatile Storage).

---

## 5. ESP-NOW Protocol Implementation

ESP-NOW is a fast, connectionless protocol that bypasses the router, making it incredibly reliable for edge IoT deployments.

- **MAC Addresses:** The Main Hub's MAC address is hardcoded into the `config.h` of Node 1 and Node 2. Node 1 and 2 don't connect to a router; they just start their WiFi radio in STA mode.
- **Data Structures:** Data is sent as packed C-structs (`espnow_node1_t`, `espnow_node2_t`) to minimize overhead and ensure instant delivery.
- **Callbacks:** The Hub uses `esp_now_register_recv_cb()` to process data instantly upon arrival. Nodes use `esp_now_register_send_cb()` to verify delivery success.

### 5.1 Firmware Sequence Diagram
```mermaid
sequenceDiagram
    participant N1 as Node 1 (Water Quality)
    participant N2 as Node 2 (Environment)
    participant Hub as Main Hub
    participant Firebase as Firebase RTDB
    
    N1->>N1: Wake up, Read Sensors
    N2->>N2: Wake up, Read Sensors
    
    N1-->>Hub: ESP-NOW Broadcast (C-struct)
    N1->>N1: Deep Sleep
    
    N2-->>Hub: ESP-NOW Broadcast (C-struct)
    
    Hub->>Hub: Merge payloads & Add NTP Timestamp
    Hub-->>Firebase: HTTPS POST JSON (Direct)
```

---

## 6. BLE Offline Sync Implementation

To solve the lack of an SD Card module, the system buffers data on the user's mobile device.

- **Service UUID:** A custom UUID is defined for the Desalination System (e.g., `4fafc201-1fb5-459e-8fcc-c5c9c331914b`).
- **Notify Characteristic:** A read/notify characteristic streams the aggregated system JSON payload to the Flet mobile app.
- **Write Characteristic:** An RX characteristic allows the mobile app to send JSON commands back to the Hub (e.g. WiFi credentials).
- **Mobile App Role:** The Flet app listens for notifications, and saves every payload to a local SQLite database (`sensor_data.sqlite`).
- **Cloud Sync:** When the mobile app detects an active Internet connection, a background `sync.py` worker automatically uploads the SQLite queue to the FastAPI backend, ensuring zero data loss during power/network outages at the installation site.

---

## 7. Source Code Reference

| Folder | Key Files | Purpose |
|---|---|---|
| `firmware/Node1_WaterQuality/` | `Node1_WaterQuality.ino`, `config.h` | Core water sensing & pump control. |
| `firmware/Node2_Environment/` | `Node2_Environment.ino`, `config.h` | Environment and fan control. |
| `firmware/Main_Hub/` | `Main_Hub.ino`, `config.h` | Central hub, Display UI, and mobile BLE integration. |

---

## 8. Testing Procedures

1. **Upload Node Firmware:** Flash Node 1 and Node 2. Monitor their serial outputs to ensure ESP-NOW packets are being sent successfully.
2. **Verify Hub Reception:** Flash the Main Hub. Ensure the serial monitor logs incoming packets from both nodes correctly.
3. **Verify TFT Display:** Check that sensor values update on the 5-inch screen within 5 seconds of a physical change.
4. **Test BLE Connection:** Use a mobile app like *nRF Connect* (or your Flet app) to bond with the Hub and subscribe to the characteristic. Ensure data flows continuously.

---

## 9. Validation Checklist

- [ ] Node 1 successfully compiles and sends data via ESP-NOW (including all 7 sensor types)
- [ ] Pressure sensor reads expected 0 bar at atmospheric pressure
- [ ] Node 2 successfully compiles and sends data via ESP-NOW
- [ ] Main Hub successfully receives data from both nodes asynchronously
- [ ] TFT Display renders UI and updates in real-time without blocking
- [ ] BLE Server starts and broadcasts correctly
- [ ] Flet Mobile App successfully pairs and receives BLE data

---

> [!IMPORTANT]  
> Phase 3 represents the completion of the Edge Layer. The physical devices are now fully autonomous IoT nodes capable of interacting with the local display and the mobile app.

---

**Have you completed this phase?**

Reply with **"Phase Completed"** to proceed to **Phase 4: Backend API Development** *(FastAPI on Vercel, Firebase Admin integration, and ML prediction endpoints).*

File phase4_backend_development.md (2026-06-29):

# 🚀 Phase 4 — Backend API Development (FastAPI on Vercel)

---

## 📋 Table of Contents

1. [Objectives](#1-objectives)
2. [Architecture Overview](#2-architecture-overview)
3. [Project Structure](#3-project-structure)
4. [Configuration & Secrets](#4-configuration--secrets)
5. [Firebase Integration](#5-firebase-integration)
6. [ML Prediction Service](#6-ml-prediction-service)
7. [API Endpoints Reference](#7-api-endpoints-reference)
8. [Vercel Deployment](#8-vercel-deployment)
9. [Testing Procedures](#9-testing-procedures)
10. [Validation Checklist](#10-validation-checklist)

---

## 1. Objectives

| # | Objective | Priority |
|---|---|---|
| 1 | Build a production-ready FastAPI backend deployable to Vercel | 🔴 Critical |
| 2 | Integrate both trained ML models (Water Quality + Membrane Status) as REST endpoints | 🔴 Critical |
| 3 | Connect to Firebase Realtime Database using the Admin SDK | 🔴 Critical |
| 4 | Build an alert evaluation engine based on WHO water quality thresholds | 🟠 High |
| 5 | Proxy the Gemini AI API for the in-app chatbot | 🟠 High |
| 6 | Expose a system health endpoint for Vercel uptime monitoring | 🟡 Medium |

---

## 2. Architecture Overview

```mermaid
graph TD
    MobileApp[Flet Mobile App] -- HTTPS POST (Sync) --> FastAPI
    Dashboard[Web Dashboard] -- HTTP GET/POST --> FastAPI
    MainHub[Main Hub] -- HTTPS POST --> Firebase[(Firebase RTDB)]

    FastAPI -- Firebase Admin SDK --> Firebase
    FastAPI -- loads pkl --> MLModels[RF Models: water_quality + membrane]
    FastAPI -- HTTPS --> Gemini[Gemini 2.5 Flash API]
```

- **FastAPI** is the single backend, handling ML inference, alerting, and AI chat, as well as ingesting offline-synced data from the mobile app.
- **Main Hub** pushes live data directly to Firebase RTDB, bypassing the backend for real-time sensor updates.
- **Firebase RTDB** is the cloud store for live data, historical logs, and alerts.
- **ML models** are bundled inside the backend — no separate ML service needed.
- Deployed on **Vercel** as Python Serverless Functions.

---
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

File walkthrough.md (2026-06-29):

# Phase 3 Firmware Development Walkthrough

I have successfully replaced the basic hardware test sketch with a complete, production-ready, state-machine-driven firmware architecture for the ESP32.

## Key Accomplishments
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

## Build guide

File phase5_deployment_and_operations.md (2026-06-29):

# 🚢 Phase 5 — Deployment, Testing, and Operations

This phase provides a comprehensive guide on how to deploy and test the entire Smart Water Desalination System from end-to-end, covering the Hardware, Backend, Web Dashboard, and Mobile App.

---

## 📋 Table of Contents
1. [Hardware Deployment & Testing](#1-hardware-deployment--testing)
2. [Backend API Deployment & Testing](#2-backend-api-deployment--testing)
3. [Web Dashboard Deployment & Testing](#3-web-dashboard-deployment--testing)
4. [Mobile App Testing & Usage](#4-mobile-app-testing--usage)
5. [End-to-End System Test Flow](#5-end-to-end-system-test-flow)

---

## 1. Hardware Deployment & Testing

The hardware consists of 3 ESP32 nodes. You must flash them in order and verify their connections.

### 1.1 Preparing the Main Hub
1. Open the `Main_Hub` folder in Arduino IDE or PlatformIO.
2. Ensure you have installed the required libraries: `Firebase ESP Client`, `ArduinoJson`, `BLEDevice`.
3. Open `config.h` and verify your `FIREBASE_API_KEY` and `FIREBASE_DATABASE_URL` are correct.
4. **Flash the Main Hub** to an ESP32.
5. **Testing**: 
   - Open the Serial Monitor at `115200` baud.
   - You should see it attempt to connect to WiFi. If it fails, it will fall back to BLE-only mode.
   - You should see `[ESP-NOW] Ready.` indicating the receiver is active.

### 1.2 Preparing Node 1 and Node 2
1. Open `Node1_WaterQuality` and `Node2_Environment`.
2. In each project's `config.h`, ensure the `hubAddress` matches the actual MAC address of your Main Hub ESP32.
   *(You can find the Hub's MAC address in its serial monitor during boot: `[WiFi] MAC: XX:XX:XX...`)*
3. **Flash Node 1 and Node 2**.
4. **Testing**:
   - Open the Serial Monitor for Node 1. You should see it reading mock/real sensors and outputting `[ESP-NOW] Delivery Success`.
   - Look back at the **Main Hub Serial Monitor**. You should see `[ESP-NOW] Node 1 data received` every 5 seconds.

### 1.3 Testing Hardware Internet Connection
1. With the Hub connected to your local WiFi, watch its Serial Monitor.
2. Every 5 seconds (when it receives data), it should print `[Firebase] Live data pushed OK.`
3. Go to your Firebase Console online and verify the data is appearing under `/devices/device_001/live_data`.

---

## 2. Backend API Deployment & Testing

The FastAPI backend handles ML predictions, historical alerts, and offline sync ingestion.

### 2.1 Local Testing
1. Navigate to the `backend` folder in your terminal.
2. Ensure your `.env` file contains `FIREBASE_DATABASE_URL` and `FIREBASE_SERVICE_ACCOUNT_PATH`.
3. Start the server:
   ```bash
   uvicorn app.main:app --reload
   ```
4. **Testing**:
   - Open `http://127.0.0.1:8000/docs` in your browser.
   - Test the `GET /api/v1/sensors/live` endpoint. It should successfully fetch the data that the Main Hub just pushed to Firebase.
   - Test the `GET /api/v1/alerts/history` endpoint to see if the alert engine is evaluating the data.

### 2.2 Vercel Deployment
To deploy the backend to the cloud permanently:
1. Install the Vercel CLI: `npm i -g vercel`
2. Run `vercel login` and authenticate.
3. Run `vercel` in the `backend` directory.
4. Add your `.env` variables in the Vercel project settings dashboard.
5. Your API will be live at `https://your-project.vercel.app`.

---

## 3. Web Dashboard Deployment & Testing

The Web Dashboard visualizes the data sitting in Firebase via your FastAPI backend.

### 3.1 Local Testing
1. Ensure your FastAPI backend is running locally at `http://127.0.0.1:8000`.
2. Open the `dashboard/web/index.html` file in any modern browser.
3. **Testing**:
   - The dashboard should say "Live" (pulsing green indicator) in the bottom left.
   - The KPIs (pH, TDS, Turbidity) should update every 5 seconds as the Main Hub pushes new data.
   - Click the **History** tab. You should see a multi-line chart populating.
   - If the Hardware pushes a high TDS value (e.g., > 1000), an **Alert Toast** should slide in from the top right.

---

## 4. Mobile App Testing & Usage

The Flet mobile app provides offline viewing, BLE connection to the Hub, and WiFi provisioning.

### 4.1 Running the App on PC (Desktop Mode)
1. Navigate to the `mobile/src` folder.
2. Run `python main.py`.
3. The app will open in a window shaped like a mobile phone.

### 4.2 Testing Virtual BLE (No Hardware Needed)
1. Go to the **Settings** tab (gear icon).
2. Ensure "Use Virtual BLE (Testing)" is toggled **ON**.
3. Go back to the **Live** tab. The app will simulate incoming BLE data, display it, and save it to the local SQLite database.
4. Go to the **History** tab to view the SQLite chart.

### 4.3 Testing Real Hardware BLE
1. Ensure your Main Hub ESP32 is powered on.
2. In the App **Settings** tab, toggle "Use Virtual BLE" to **OFF** and set the BLE Device Name to `AquaMonitor`.
3. Restart the app.
4. The app will scan for the ESP32, connect, and stream the live JSON payload.

### 4.4 Provisioning WiFi to the Hardware
If the Main Hub loses WiFi, you can fix it from the App:
1. Ensure the app is connected to the Hub via BLE.
2. Go to the **WiFi** tab in the app.
3. Enter your Home SSID and Password.
4. Click **Send via BLE**. The Hub's Serial Monitor will show `[BLE CMD] Setting WiFi: SSID=...` and it will automatically reconnect.

---

## 5. End-to-End System Test Flow

To prove the entire system works together flawlessly, run this final integration test:

1. **Power up Node 1 and Node 2**.
2. **Power up the Main Hub** (Ensure it is out of WiFi range or given the wrong password initially).
3. **Open the Mobile App** and connect to the Hub via BLE.
   - *Result*: You should see live sensor data streaming to your phone, proving Node1 -> ESP-NOW -> Hub -> BLE -> Phone works.
4. **Go to the WiFi Tab** in the App and send the correct WiFi credentials.
   - *Result*: The Hub connects to WiFi.
5. **Open the Web Dashboard** on your PC.
   - *Result*: The dashboard immediately starts showing the live data, proving Hub -> Firebase -> Backend -> Dashboard works.
6. **Disconnect the Hub from WiFi** temporarily.
   - *Result*: The mobile app continues to receive BLE data and saves it locally.
7. **Reconnect the Hub to WiFi**.
   - *Result*: The mobile app's background worker senses the internet connection and automatically uploads the saved offline data to the FastAPI `/ingest` endpoint, updating the cloud history.

**🎉 System Validation Complete!**

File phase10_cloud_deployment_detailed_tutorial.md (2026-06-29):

# 🚀 Vercel Deployment — Detailed Walkthrough

---

## 🧰 What You Need Before Starting

- [ ] Your project folder: `d:\Projects\Arduino Projects\Water Desalination`
- [ ] The file `backend\serviceAccountKey.json` exists (downloaded from Firebase Console)
- [ ] A [GitHub](https://github.com) account (free)
- [ ] A [Vercel](https://vercel.com) account (free — sign in with GitHub)

---

## Step 1 — Encode the Firebase Service Account

Vercel cannot read files on your hard drive. Instead, you convert `serviceAccountKey.json` into a single long text string (base64) and paste it as an environment variable.

### Open PowerShell in the project folder

Right-click the folder `d:\Projects\Arduino Projects\Water Desalination` in File Explorer → **"Open in Terminal"**

### Run this exact command:

```powershell
[Convert]::ToBase64String(
    [IO.File]::ReadAllBytes("backend\serviceAccountKey.json")
) | Set-Clipboard
```

> **What happens:** The entire contents of `serviceAccountKey.json` get encoded and silently copied to your clipboard. Nothing will print — that's correct. The encoded string will be several hundred characters long.

### Verify it worked

```powershell
# Paste and check the first 50 characters
[Convert]::ToBase64String(
    [IO.File]::ReadAllBytes("backend\serviceAccountKey.json")
) | ForEach-Object { $_.Substring(0, 50) }
```

You should see something like: `ewogICJ0eXBlIjogInNlcnZpY2VfYWNjb3VudCIsC...`

> [!IMPORTANT]
> **Save this string somewhere safe** (e.g., a temporary Notepad file) before proceeding. You'll paste it into Vercel in Step 5. If you close the terminal, run the command again to re-copy it.

---

## Step 2 — Push the Project to GitHub

### 2.1 Initialize Git (if not already done)

```powershell
cd "d:\Projects\Arduino Projects\Water Desalination"
git init
```

If git is already initialized, skip to 2.2.

### 2.2 Safety check — make sure secrets are excluded

```powershell
git status
```

**Look at the output carefully.** You should NOT see any of these files listed:
- `backend/serviceAccountKey.json`
- `backend/.env`
- `*.sqlite` or `*.db`

If you see them, your `.gitignore` isn't working — stop and check it before continuing.

### 2.3 Stage and commit everything

```powershell
git add .
git commit -m "Phase 10: Vercel deployment ready"
```

### 2.4 Create a GitHub repository

1. Go to **[github.com/new](https://github.com/new)**
2. Repository name: `water-desalination` (or any name)
3. Set to **Private** (recommended — protects your code)
4. Click **"Create repository"**
5. GitHub shows you a page with setup commands. Copy the remote URL — it looks like:
   ```
   https://github.com/YOUR_USERNAME/water-desalination.git
   ```

### 2.5 Connect and push

```powershell
git remote add origin https://github.com/YOUR_USERNAME/water-desalination.git
git branch -M main
git push -u origin main
```

You'll be prompted for your GitHub username and password (or a personal access token if you have 2FA enabled).

> ✅ **Success check:** Refresh your GitHub repo page — you should see all the project files listed, including `backend/`, `mobile/`, `README.md`, etc.

---

## Step 3 — Create a Vercel Account

1. Go to **[vercel.com](https://vercel.com)**
2. Click **"Sign Up"**
3. Choose **"Continue with GitHub"** — this lets Vercel access your repos directly
4. Authorize Vercel on GitHub when prompted
5. On the Vercel dashboard, you'll see **"No projects yet"**

---

## Step 4 — Import the Project into Vercel

### 4.1 Click "Add New… → Project"

In the top-right of the Vercel dashboard, click the **"Add New…"** button → select **"Project"**

### 4.2 Import from GitHub

- Vercel shows a list of your GitHub repos
- Find **`water-desalination`** and click **"Import"**

### 4.3 Configure the project — this is the critical step

You'll see a **"Configure Project"** screen. Fill it in exactly as follows:

| Setting | Value |
|---|---|
| **Project Name** | `water-desalination` (or any name) |
| **Framework Preset** | `Other` |
| **Root Directory** | Click **"Edit"** → type `backend` → click **"Continue"** |
| **Build Command** | Leave blank (auto-detected) |
| **Output Directory** | Leave blank |
| **Install Command** | Leave blank (Vercel auto-runs `pip install -r requirements.txt`) |

> [!IMPORTANT]
> Setting **Root Directory = `backend`** is crucial. It tells Vercel to deploy only the `backend/` subfolder where `vercel.json` and `main.py` are. If you skip this, Vercel will try to deploy the entire project root and fail.

### What it looks like after setting Root Directory:

```
Root Directory: backend ✓
  ├── main.py            ← Vercel's entry point
  ├── vercel.json        ← Deployment config
  ├── requirements.txt   ← Dependencies
  ├── app/               ← FastAPI app
  └── ml/                ← .pkl model files
```

---

## Step 5 — Set Environment Variables

**Do not click "Deploy" yet.** Scroll down to the **"Environment Variables"** section on the same Configure Project screen.

Add each variable one at a time by clicking **"Add"**:

---

### Variable 1: `FIREBASE_DATABASE_URL`

- **Name:** `FIREBASE_DATABASE_URL`
- **Value:** Your Firebase RTDB URL

**How to find it:**
1. Go to [console.firebase.google.com](https://console.firebase.google.com)
2. Select your project
3. Left menu → **"Realtime Database"**
4. At the top of the page, copy the URL — it looks like:
   ```
   https://water-desalination-8638c-default-rtdb.europe-west1.firebasedatabase.app
   ```

---

### Variable 2: `FIREBASE_SERVICE_ACCOUNT_BASE64`

- **Name:** `FIREBASE_SERVICE_ACCOUNT_BASE64`
- **Value:** Paste the base64 string you copied in Step 1

> [!IMPORTANT]
> This is a very long string. Paste the **entire** thing. It starts with `eyJ` and ends with a `=` or `==`. Make sure there are no spaces or line breaks.

---

### Variable 3: `GEMINI_API_KEY`

- **Name:** `GEMINI_API_KEY`
- **Value:** Your Gemini API key

**How to find it:**
1. Go to [aistudio.google.com](https://aistudio.google.com)
2. Click **"Get API Key"** in the top menu
3. Copy the key (starts with `AQ.` or `AI...`)

---

### Variable 4: `API_KEY`

- **Name:** `API_KEY`
- **Value:** `aquamonitor-secret-key-2024`

> This is your custom key that protects the `/ingest` endpoint. You can use any value — just keep it secret and remember it.

---

### After adding all 4 variables, check the boxes:

Make sure all 4 variables have these environments checked:
- ✅ Production
- ✅ Preview
- ✅ Development

---

## Step 6 — Deploy

Click the **"Deploy"** button.

### What happens during the build (watch the logs):

```
[10:00] Cloning github.com/YOUR_USERNAME/water-desalination...
[10:02] Detected Python project
[10:02] Running: pip install -r requirements.txt
[10:15] Installing: fastapi, uvicorn, firebase-admin, scikit-learn...
[10:45] Build completed
[10:46] Deploying...
[10:47] ✅ Deployment ready!
```

> The build takes **1–3 minutes** — the ML packages (`scikit-learn`, `firebase-admin`) are large.

### Success screen

You'll see a **confetti animation** and your deployment URL:
```
🎉 Congratulations!
https://water-desalination-abc123.vercel.app
```

**Copy this URL** — you'll need it in Step 8.

---

## Step 7 — Verify the Deployment

Open your browser and test each URL. Replace `your-project` with your actual Vercel URL.

### ✅ Test 1 — Root health check
```
https://your-project.vercel.app/
```
**Expected:**
```json
{"message": "Water Desalination API is running.", "docs": "/docs"}
```

### ✅ Test 2 — API documentation
```
https://your-project.vercel.app/docs
```
**Expected:** A Swagger UI page showing all your endpoints. Click on any `GET` endpoint → "Try it out" → "Execute" to test live.

### ✅ Test 3 — Live sensor data
```
https://your-project.vercel.app/api/v1/sensors/live
```
**Expected:**
```json
{"status": "ok", "data": {"ph_feed": 7.2, "tds_feed": 300, ...}}
```
or `{"status": "no_data"}` if the hardware hasn't pushed recently.

### ✅ Test 4 — ML prediction (run from browser)
```
https://your-project.vercel.app/api/v1/predict/run
```
**Expected:**
```json
{
  "status": "ok",
  "predictions": {
    "water_quality": {"label": "good", "confidence": 94.2},
    "membrane_status": {"label": "good", "confidence": 87.5}
  }
}
```

### ✅ Test 5 — Security check (use PowerShell)

Without the API key — should be rejected:
```powershell
Invoke-RestMethod -Uri "https://your-project.vercel.app/api/v1/sensors/ingest" `
  -Method POST `
  -ContentType "application/json" `
  -Body '{"ph_feed": 7.2}'
```
**Expected:** `403 Forbidden` — `"Invalid or missing API key"`

With the correct key — should succeed:
```powershell
$headers = @{ "X-API-Key" = "aquamonitor-secret-key-2024" }
Invoke-RestMethod -Uri "https://your-project.vercel.app/api/v1/sensors/ingest" `
  -Method POST `
  -ContentType "application/json" `
  -Headers $headers `
  -Body '{"ph_feed": 7.2, "tds_feed": 300}'
```
**Expected:** `{"status": "ok", "timestamp": "2026-..."}`

---

## Step 8 — Update the Mobile App

Now that the backend is live in the cloud, point the mobile app to it.

1. Run the mobile app:
   ```powershell
   cd "d:\Projects\Arduino Projects\Water Desalination\mobile\src"
   python main.py
   ```
2. Click the **Settings** tab (gear icon, bottom right)
3. In **"FastAPI Backend URL"**, clear the current value and type:
   ```
   https://your-project.vercel.app
   ```
4. Click **"Save Settings"**
5. The app will now sync data to the cloud backend — even when you're not on your home WiFi

---

## Step 9 — Update CORS (Final Step)

Now that you know your Vercel URL, add it to the CORS whitelist so the web dashboard can call the API from a browser.

Open `backend/main.py` and update:

```python
ALLOWED_ORIGINS = [
    "http://localhost",
    "http://127.0.0.1",
    "https://your-project.vercel.app",   # ← Add YOUR actual URL here
]
```

Then commit and push:
```powershell
cd "d:\Projects\Arduino Projects\Water Desalination"
git add backend/main.py
git commit -m "Add Vercel URL to CORS whitelist"
git push
```

> Vercel will automatically detect the push and redeploy within ~90 seconds. No manual action needed.

---

## 🎉 You're Done!

Your backend is now:
- ✅ Running 24/7 on Vercel (free tier)
- ✅ Accessible from anywhere in the world
- ✅ Protected with an API key on write endpoints
- ✅ Automatically redeploying on every `git push`

**Your live API URL:** `https://your-project.vercel.app`  
**Interactive docs:** `https://your-project.vercel.app/docs`

---

## 🔧 If Something Goes Wrong

| Problem | What to check |
|---|---|
| Build fails at `pip install` | Check `backend/requirements.txt` has `pydantic-settings>=2.2.0` |
| "No module named X" error | The module is missing from `requirements.txt` — add it and push again |
| Firebase 403 / credential error | The base64 string was truncated — re-encode and update the env var in Vercel dashboard |
| All endpoints return 500 | Check **Function Logs** in Vercel dashboard → your project → Deployments → click latest → Logs |
| ML model not found | Verify `backend/ml/*.pkl` files are committed to Git (not in `.gitignore`) |

### How to view live error logs on Vercel:
1. Go to [vercel.com](https://vercel.com) → your project
2. Click **"Deployments"** tab
3. Click the latest deployment
4. Click **"Functions"** → click any function name
5. Click **"Logs"** — shows real-time errors

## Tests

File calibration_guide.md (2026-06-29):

# Analog Sensor Calibration Guide

This guide will walk you through calibrating the analog sensors across the new 3-Node Architecture to ensure accurate readings. Since we are using voltage dividers and analog-to-digital converters (ADC), software calibration is essential.

All calibration constants are stored in the respective node's `config.h` file (e.g., `firmware/Node1_WaterQuality/config.h` and `firmware/Node2_Environment/config.h`). 

---

## NODE 1 (Water Quality Sensors)

### 1. pH Sensor Calibration

The pH sensor requires a two-point calibration to find the midpoint voltage (at pH 7.0) and the slope.

#### Materials Needed:
- pH 7.0 buffer solution
- pH 4.0 buffer solution
- Distilled water (for rinsing)

#### Steps:
1. **Rinse** the pH probe in distilled water and dry it gently.
2. **Submerge** the probe in the **pH 7.0** buffer solution.
3. Wait 1 minute for the reading to stabilize.
4. Check the Serial Monitor. Look at the raw voltage reading (or write a quick `Serial.println(readADC_Voltage(PIN_PH))` in the `Node1_WaterQuality.ino` loop). Let's say the voltage reads `2.52V`.
5. Open `Node1_WaterQuality/config.h` and update:
   ```c
   #define PH_VOLTAGE_AT_PH7       2.52f
   ```
6. **Rinse** the probe again in distilled water.
7. **Submerge** the probe in the **pH 4.0** buffer solution.
8. Wait 1 minute. Note the new voltage (e.g., `3.05V`).
9. **Calculate the Slope:**
   ```
   Slope = (Voltage at pH 4.0 - Voltage at pH 7.0) / (4.0 - 7.0)
   Slope = (3.05 - 2.52) / -3.0
   Slope = -0.176
   ```
10. Open `config.h` and update:
    ```c
    #define PH_SLOPE                -0.176f
    ```

---

### 2. TDS Sensor Calibration

The TDS sensor formula relies on a temperature-compensated voltage. It usually doesn't need a complex slope adjustment if you are using standard 3.3V TDS modules, but you can calibrate it against a known standard.

#### Steps:
1. Ensure a temperature sensor is submerged in the same solution, as TDS relies heavily on accurate temperature compensation!
2. **Submerge** the TDS probe in a known calibration solution (e.g., 342 ppm).
3. Look at the Serial Monitor output for the calculated TDS value.
4. If the code outputs `300 ppm` but your solution is `342 ppm`, calculate the factor: `342 / 300 = 1.14`.
5. Change `TDS_CALIBRATION_FACTOR` in `config.h` from `1.0f` to `1.14f`.

---

### 3. Turbidity Sensor Calibration

The turbidity sensor outputs an inverse analog voltage: highest voltage when the water is clear (0 NTU), and lower voltage as it gets murkier.

#### Steps:
1. **Submerge** the turbidity sensor in pure distilled water (0 NTU).
2. Check the Serial Monitor for the raw ADC voltage (after the voltage divider multiplier is applied). Let's say it reads `4.15V`.
3. Open `config.h` and update the zero-point voltage:
   ```c
   #define TURBIDITY_VOLTAGE_CLEAR 4.15f
   ```

> [!WARNING]
> The Turbidity sensor is highly sensitive to ambient light. **Always calibrate under the same lighting conditions as the final installation.**

---

## NODE 2 (Environment Sensors)

### 4. MQ-Series Gas Sensor Calibration (Air Quality)

MQ sensors (like MQ-2, MQ-135) require a burn-in period and a baseline calibration in clean air. The sensor resistance changes based on target gas concentration.

#### Steps:
1. **Burn-in:** Leave the sensor powered on for **24 to 48 hours** before first use to burn off factory impurities.
2. **Clean Air Baseline (Ro calculation):**
   - Place the sensor in a known clean-air environment (e.g., outdoors in fresh air).
   - Read the analog voltage from the sensor.
   - Calculate the sensor resistance (Rs) using the voltage divider equation.
   - For clean air, the ratio `Rs/Ro` is a constant found in the datasheet (e.g., for MQ-135, `Rs/Ro ≈ 3.6` in clean air).
   - Divide your calculated Rs by this constant to find **Ro** (the base resistance).
3. Open `Node2_Environment/config.h` and update your `Ro` constant:
   ```c
   #define MQ_SENSOR_RO  15.5f  // Example base resistance in kilo-ohms
   ```
4. **Target Gas Calibration (Optional):** If you need absolute ppm for a specific gas (like CO2), you must expose it to a known concentration (e.g., 400ppm CO2) and adjust the scaling curve factor in your code.

---

### 5. Ultrasonic Sensor Calibration (Tank Levels)

Ultrasonic sensors (HC-SR04 or similar waterproof JSN-SR04T) measure time-of-flight. They don't need voltage calibration, but they do require geometric calibration for your specific tanks.

#### Steps:
1. Mount the ultrasonic sensor at the very top of the tank.
2. Measure the physical distance from the sensor to the bottom of the empty tank (e.g., `100 cm`). This is `TANK_DEPTH_CM`.
3. Measure the distance from the sensor to the water surface when the tank is at its absolute maximum safe capacity (e.g., `10 cm`). This is `TANK_EMPTY_GAP_CM`.
4. Update these constants in `Node2_Environment/config.h` so the code can map the distance reading (cm) to a percentage (0-100%).

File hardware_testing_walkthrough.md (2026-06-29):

# Hardware & Software Testing Walkthrough

This guide walks you through the end-to-end testing of your Water Desalination system, ensuring the ESP32 hardware, Mobile App, and Web Dashboard all communicate correctly.

## Prerequisites
1. **Node 1 (Water Quality)** and **Main Hub** ESP32s are flashed with the updated firmware.
2. The FastAPI backend and Web Dashboard are installed.
3. The Mobile App dependencies (`flet`, `bleak`, etc.) are installed.

---

## Step 1: Start the Local Servers
First, start your backend API and web dashboard. 

Open a terminal in the root of your project folder (`D:\Projects\Arduino Projects\Water Desalination`) and run:
```bash
python run.py
```
> [!NOTE]
> This command starts the FastAPI backend on `http://127.0.0.1:8000` and the web dashboard on `http://127.0.0.1:54321`. Leave this terminal running in the background.

## Step 2: Power on the Hardware
1. Power up **Node 1**. It will immediately wake up, take sensor readings, broadcast them via ESP-NOW, and go back to deep sleep.
2. Power up the **Main Hub**. It will begin advertising its BLE service (named `AquaMonitor`) and wait for WiFi credentials if it doesn't already have them.

## Step 3: Launch the Mobile App
Open a new terminal, navigate to the mobile source directory, and start the app:
```bash
cd mobile/src
python main.py
```

> [!TIP]
> If you don't have Bluetooth enabled on your PC, you can test the UI by going to the **Settings** tab in the mobile app and enabling **Use Virtual BLE (Testing)**, then restarting the app.

## Step 4: Configure Hub WiFi via Mobile App
We need to tell the Main Hub how to connect to your local router (e.g., `Mahmoud`).

1. In the mobile app, navigate to the **WiFi Setup** tab.
2. Enter your router's **SSID** and **Password**.
3. Click **Send via BLE**.
4. **Expected Result**: The app should confirm the credentials were sent. If you monitor the Main Hub's serial output via Arduino IDE, you should see it receive the JSON command over BLE and attempt to connect to your Wi-Fi.

> [!IMPORTANT]
> The Main Hub *must* connect to the same Wi-Fi router that your computer (running the backend) is connected to!

## Step 5: Verify Data Flow
Once the Main Hub connects to Wi-Fi, the full pipeline will activate:

1. **ESP-NOW Link**: Node 1 wakes up (every ~30s), reads sensors, and blasts the data across all channels. The Main Hub intercepts this data.
2. **Backend Ingestion**: The Main Hub forwards the payload to your local FastAPI backend (`http://<YOUR_PC_IP>:8000/api/v1/sensors/ingest`).
3. **Web Dashboard**: Open your browser to [http://127.0.0.1:54321](http://127.0.0.1:54321). 
   - **Expected Result**: You should see the live sensor values (pH, TDS, Turbidity, etc.) updating dynamically.
4. **Mobile App Dashboard**: Navigate to the **Dashboard** tab on the mobile app. 
   - **Expected Result**: The mobile app fetches the latest readings from the backend and updates the UI.

## Troubleshooting

> [!WARNING]
> **Firebase Errors:** You may see `WARNING: serviceAccountKey.json not found! Running backend without Firebase sync.` in your backend logs. This is normal if you haven't set up the backend admin SDK key yet; the local pipeline (Hardware → Local Backend → Dashboard) will still work perfectly.

> [!CAUTION]
> **No Data on Dashboard?** 
> - Ensure your `config.h` in the Main Hub has `BACKEND_URL` set to your PC's actual local IP address (e.g., `192.168.1.X`), not `127.0.0.1`. The ESP32 cannot resolve `127.0.0.1` to your computer.
> - Verify Node 1 and Main Hub are close enough for ESP-NOW range.

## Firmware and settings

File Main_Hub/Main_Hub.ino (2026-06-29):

/*
 * ============================================================
 *  Smart Water Desalination Monitoring System
 *  Firmware: Main Hub — Communication & BLE Server
 *  Version:  2.0.0
 *  Role:
 *    - Receives full sensor data from Node 1 via ESP-NOW
 *    - Receives environment data from Node 2 via ESP-NOW
 *    - Merges all data into one JSON payload
 *    - Streams merged JSON to mobile app over BLE (notify)
 *    - Receives BLE commands from app (write):
 *        {"cmd":"set_wifi","ssid":"...","pass":"..."} → reconnect WiFi
 *        {"cmd":"pump_on"} / {"cmd":"pump_off"}       → future relay
 *    - When WiFi is connected, pushes merged data to FastAPI backend
 *  Phase: 3 — ESP32 Firmware Development
 * ============================================================
 */

#include <WiFi.h>
#include <esp_now.h>
#include <BLEDevice.h>
#include <BLEServer.h>
#include <BLEUtils.h>
#include <BLE2902.h>
#include <ArduinoJson.h>
#include <Preferences.h>
#include "config.h"
#include "firebase_client.h"
typedef struct __attribute__((packed)) espnow_node1_t {
    float ph_feed;
    float ph_permeate;
    float tds_feed;
    float tds_permeate;
    float turbidity_feed;
    float temperature_feed;
    float temperature_permeate;
    float pressure_feed;
    float flow_rate_feed;
    float flow_rate_permeate;
    float recovery_rate;
    float rejection_rate;
    bool  level_feed_full;
    bool  level_product_full;
    bool  pump_running;
    bool  valve_open;
    uint32_t uptime_seconds;
} espnow_node1_t;

// ============================================================
//  Node 2 — Environment struct (must match Node2 firmware)
// ============================================================
typedef struct __attribute__((packed)) espnow_node2_t {
    float tank1_level_cm;
    float tank2_level_cm;
    float ambient_temp;
    float ambient_humidity;
    float gas_1_ppm;
    float gas_2_ppm;
    float water_temp_1;
    float water_temp_2;
    bool  fan_1_status;
    bool  fan_2_status;
    bool  fan_3_status;
} espnow_node2_t;

// ============================================================
//  Global State
// ============================================================
espnow_node1_t dataNode1 = {};
espnow_node2_t dataNode2 = {};
bool node1Updated = false;
bool node2Updated = false;
unsigned long lastBleNotify    = 0;
unsigned long lastFirebasePush = 0;
const unsigned long BLE_INTERVAL_MS      = 3000;
const unsigned long FIREBASE_INTERVAL_MS = 5000;
unsigned int push_counter = 0;

// ============================================================
//  BLE
// ============================================================
BLEServer*         pServer         = nullptr;
BLECharacteristic* pNotifyChar     = nullptr;  // App reads sensor data
BLECharacteristic* pWriteChar      = nullptr;  // App sends commands
bool deviceConnected = false;

Preferences prefs;

// ============================================================
//  BLE Server Callbacks
// ============================================================
class HubServerCallbacks : public BLEServerCallbacks {
    void onConnect(BLEServer*) override {
        deviceConnected = true;
        Serial.println("[BLE] Mobile app connected.");
    }
    void onDisconnect(BLEServer* s) override {
        deviceConnected = false;
        Serial.println("[BLE] Mobile app disconnected. Re-advertising...");
        BLEDevice::startAdvertising();
    }
};

// ============================================================
//  BLE Write Characteristic Callbacks (commands from app)
// ============================================================
class CommandCallbacks : public BLECharacteristicCallbacks {
    void onWrite(BLECharacteristic* pChar) override {
        String raw = pChar->getValue();
        if (raw.isEmpty()) return;
        Serial.printf("[BLE CMD] Received: %s\n", raw.c_str());

        StaticJsonDocument<256> doc;
        if (deserializeJson(doc, raw.c_str()) != DeserializationError::Ok) {
            Serial.println("[BLE CMD] Invalid JSON");
            return;
        }

        const char* cmd = doc["cmd"] | "";

        if (strcmp(cmd, "set_wifi") == 0) {
            const char* ssid = doc["ssid"] | "";
            const char* pass = doc["pass"] | "";
            Serial.printf("[BLE CMD] Setting WiFi: SSID=%s\n", ssid);
            prefs.begin("hub_cfg", false);
            prefs.putString("wifi_ssid", ssid);
            prefs.putString("wifi_pass", pass);
            prefs.end();
            // Reconnect
            WiFi.disconnect(true);
            delay(500);
            WiFi.begin(ssid, pass);
            Serial.println("[WiFi] Reconnecting with new credentials...");

        } else if (strcmp(cmd, "pump_on") == 0) {
            Serial.println("[BLE CMD] pump_on → (future: relay control)");
            // TODO: if Hub has a relay, control it here

        } else if (strcmp(cmd, "pump_off") == 0) {
            Serial.println("[BLE CMD] pump_off → (future: relay control)");

        } else {
            Serial.printf("[BLE CMD] Unknown command: %s\n", cmd);
        }
    }
};

// ============================================================
//  ESP-NOW Receive Callback
// ============================================================
void OnDataRecv(const esp_now_recv_info* info, const uint8_t* data, int len) {
    if (len == sizeof(espnow_node1_t)) {
        memcpy(&dataNode1, data, sizeof(dataNode1));
        node1Updated = true;
        Serial.println("[ESP-NOW] Node 1 data received.");
    } else if (len == sizeof(espnow_node2_t)) {
        memcpy(&dataNode2, data, sizeof(dataNode2));
        node2Updated = true;
        Serial.println("[ESP-NOW] Node 2 data received.");
    } else {
        Serial.printf("[ESP-NOW] Unknown packet len=%d\n", len);
    }
}

// ============================================================
//  Build merged JSON payload from Node1 + Node2
// ============================================================
String buildMergedJson() {
    StaticJsonDocument<1024> doc;
    // Node 1 fields
    doc["ph_feed"]                = dataNode1.ph_feed;
    doc["ph_permeate"]            = dataNode1.ph_permeate;
    doc["tds_feed"]               = dataNode1.tds_feed;
    doc["tds_permeate"]           = dataNode1.tds_permeate;
    doc["turbidity_feed"]         = dataNode1.turbidity_feed;
    doc["temperature_feed"]       = dataNode1.temperature_feed;
    doc["temperature_permeate"]   = dataNode1.temperature_permeate;
    doc["pressure_feed"]          = dataNode1.pressure_feed;
    doc["flow_rate_feed"]         = dataNode1.flow_rate_feed;
    doc["flow_rate_permeate"]     = dataNode1.flow_rate_permeate;
    doc["recovery_rate"]          = dataNode1.recovery_rate;
    doc["rejection_rate"]         = dataNode1.rejection_rate;
    doc["level_feed_full"]        = dataNode1.level_feed_full;
    doc["level_product_full"]     = dataNode1.level_product_full;
    doc["pump_status"]            = dataNode1.pump_running;
    doc["valve_status"]           = dataNode1.valve_open;
    doc["uptime_seconds"]         = dataNode1.uptime_seconds;
    // Node 2 fields
    doc["tank1_level_cm"]         = dataNode2.tank1_level_cm;
    doc["tank2_level_cm"]         = dataNode2.tank2_level_cm;
    doc["ambient_temp"]           = dataNode2.ambient_temp;
    doc["ambient_humidity"]       = dataNode2.ambient_humidity;
    doc["gas_1_ppm"]              = dataNode2.gas_1_ppm;
    doc["gas_2_ppm"]              = dataNode2.gas_2_ppm;
    doc["water_temp_1"]           = dataNode2.water_temp_1;
    doc["water_temp_2"]           = dataNode2.water_temp_2;
    doc["fan_1_status"]           = dataNode2.fan_1_status;
    doc["fan_2_status"]           = dataNode2.fan_2_status;
    doc["fan_3_status"]           = dataNode2.fan_3_status;

    String out;
    serializeJson(doc, out);
    return out;
}

// ============================================================
//  Build merged JSON payload specifically for Firebase
//  Injects NTP timestamp.
// ============================================================
String buildFirebaseJson() {
    StaticJsonDocument<1024> doc;
    // Node 1 fields
    doc["ph_feed"]                = dataNode1.ph_feed;
    doc["ph_permeate"]            = dataNode1.ph_permeate;
    doc["tds_feed"]               = dataNode1.tds_feed;
    doc["tds_permeate"]           = dataNode1.tds_permeate;
    doc["turbidity_feed"]         = dataNode1.turbidity_feed;
    doc["temperature_feed"]       = dataNode1.temperature_feed;
    doc["temperature_permeate"]   = dataNode1.temperature_permeate;
    doc["pressure_feed"]          = dataNode1.pressure_feed;
    doc["flow_rate_feed"]         = dataNode1.flow_rate_feed;
    doc["flow_rate_permeate"]     = dataNode1.flow_rate_permeate;
    doc["recovery_rate"]          = dataNode1.recovery_rate;
    doc["rejection_rate"]         = dataNode1.rejection_rate;
    doc["level_feed_full"]        = dataNode1.level_feed_full;
    doc["level_product_full"]     = dataNode1.level_product_full;
    doc["pump_status"]            = dataNode1.pump_running ? "running" : "stopped";
    doc["valve_status"]           = dataNode1.valve_open ? "open" : "closed";
    doc["uptime_seconds"]         = dataNode1.uptime_seconds;
    doc["timestamp"]              = getISOTimestamp();
    
    // Node 2 fields
    doc["tank1_level_cm"]         = dataNode2.tank1_level_cm;
    doc["tank2_level_cm"]         = dataNode2.tank2_level_cm;
    doc["ambient_temp"]           = dataNode2.ambient_temp;
    doc["ambient_humidity"]       = dataNode2.ambient_humidity;
    doc["gas_1_ppm"]              = dataNode2.gas_1_ppm;
    doc["gas_2_ppm"]              = dataNode2.gas_2_ppm;
    doc["water_temp_1"]           = dataNode2.water_temp_1;
    doc["water_temp_2"]           = dataNode2.water_temp_2;
    doc["fan_1_status"]           = dataNode2.fan_1_status;
    doc["fan_2_status"]           = dataNode2.fan_2_status;
    doc["fan_3_status"]           = dataNode2.fan_3_status;

    String out;
    serializeJson(doc, out);
    return out;
}

// ============================================================
//  Firebase Push (Replaced Backend HTTP push)
// ============================================================
// Removed pushToBackend. Logic shifted to loop.

// ============================================================
//  WiFi Setup — tries NVS stored credentials, then config.h defaults
// ============================================================
void wifiSetup() {
    prefs.begin("hub_cfg", true);  // read-only
    String storedSSID = prefs.getString("wifi_ssid", WIFI_SSID);
    String storedPass = prefs.getString("wifi_pass",  WIFI_PASSWORD);
    prefs.end();

    Serial.printf("[WiFi] Connecting to %s ...\n", storedSSID.c_str());
    WiFi.mode(WIFI_STA);
    WiFi.begin(storedSSID.c_str(), storedPass.c_str());

    unsigned long start = millis();
    while (WiFi.status() != WL_CONNECTED && millis() - start < WIFI_CONNECT_TIMEOUT_MS) {
        delay(250);
        Serial.print(".");
    }
    Serial.println();
    if (WiFi.status() == WL_CONNECTED) {
        Serial.printf("[WiFi] Connected! IP: %s\n", WiFi.localIP().toString().c_str());
        Serial.printf("[WiFi] MAC: %s\n", WiFi.macAddress().c_str());
    } else {
        Serial.println("[WiFi] Not connected — running BLE-only mode.");
    }
}

// ============================================================
//  BLE Setup
// ============================================================
void bleSetup() {
    BLEDevice::init(BLE_DEVICE_NAME);
    pServer = BLEDevice::createServer();
    pServer->setCallbacks(new HubServerCallbacks());

    BLEService* pService = pServer->createService(BLE_SERVICE_UUID);

    // Notify characteristic — hub → app (sensor data)
    pNotifyChar = pService->createCharacteristic(
        BLE_NOTIFY_CHAR_UUID,
        BLECharacteristic::PROPERTY_READ | BLECharacteristic::PROPERTY_NOTIFY
    );
    pNotifyChar->addDescriptor(new BLE2902());

    // Write characteristic — app → hub (commands)
    pWriteChar = pService->createCharacteristic(
        BLE_WRITE_CHAR_UUID,
        BLECharacteristic::PROPERTY_WRITE | BLECharacteristic::PROPERTY_WRITE_NR
    );
    pWriteChar->setCallbacks(new CommandCallbacks());

    pService->start();

    BLEAdvertising* pAdv = BLEDevice::getAdvertising();
    pAdv->addServiceUUID(BLE_SERVICE_UUID);
    pAdv->setScanResponse(true);
    BLEDevice::startAdvertising();

    Serial.printf("[BLE] Advertising as \"%s\"\n", BLE_DEVICE_NAME);
}

// ============================================================
//  Setup
// ============================================================
void setup() {
    Serial.begin(SERIAL_BAUD_RATE);
    delay(500);
    Serial.println("\n=== AquaMonitor Main Hub v2.0 ===");

    // WiFi must be configured before ESP-NOW
    wifiSetup();

    // ESP-NOW (runs on top of WiFi STA mode)
    if (esp_now_init() != ESP_OK) {
        Serial.println("[ESP-NOW] Init FAILED");
    } else {
        esp_now_register_recv_cb(OnDataRecv);
        Serial.println("[ESP-NOW] Ready.");
    }

    if (WiFi.status() == WL_CONNECTED) {
        ntpInit();
        firebaseInit();
    }

    // BLE Server
    bleSetup();

    Serial.println("[Hub] Ready. Waiting for ESP-NOW data from nodes...");
}

// ============================================================
//  Loop
// ============================================================
void loop() {
    unsigned long now = millis();

    // Send BLE notification every BLE_INTERVAL_MS
    if (deviceConnected && (now - lastBleNotify >= BLE_INTERVAL_MS)) {
        lastBleNotify = now;
        String payload = buildMergedJson();
        pNotifyChar->setValue(payload.c_str());
        pNotifyChar->notify();
        Serial.println("[BLE] Notified app.");
    }

    // Push to Firebase every FIREBASE_INTERVAL_MS (when WiFi available)
    if (WiFi.status() == WL_CONNECTED && (now - lastFirebasePush >= FIREBASE_INTERVAL_MS)) {
        lastFirebasePush = now;
        if (node1Updated || node2Updated) {  // Only push if we have new data
            String fbPayload = buildFirebaseJson();
            pushLiveData(fbPayload);
            
            // Push historical log every ~10 cycles (e.g., 50 seconds)
            push_counter++;
            if (push_counter % 10 == 0) {
                pushHistoricalLog(fbPayload);
                
                // Construct a mock system status
                StaticJsonDocument<256> sysDoc;
                sysDoc["online"] = true;
                sysDoc["wifi_rssi"] = WiFi.RSSI();
                sysDoc["heap_free_bytes"] = ESP.getFreeHeap();
                sysDoc["last_update"] = getISOTimestamp();
                String sysPayload;
                serializeJson(sysDoc, sysPayload);
                pushSystemStatus(sysPayload);
            }
            
            node1Updated = false;
            node2Updated = false;
        }
    }

    delay(50);
}

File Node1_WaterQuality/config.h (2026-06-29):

/*
 * ============================================================
 *  Smart Water Desalination Monitoring System
 *  Master Configuration Header
 *  File: Node1_WaterQuality/config.h
 * ============================================================
 *  Board:  ESP32S 38-pin Development Board
 *  Author: Water Desalination Project
 *  Phase:  3 — ESP32 Firmware Development
 * ============================================================
 *
 *  ⚠️  CRITICAL ESP32 ADC RULE:
 *  ADC2 pins (GPIO0,2,4,12-15,25-27) CANNOT be used for
 *  analogRead() while WiFi is active. ALL analog sensors
 *  MUST use ADC1 pins: GPIO32, GPIO33, GPIO34, GPIO35, GPIO36, GPIO39
 *
 *  ✅  GPIO27 (PIN_FLOW_PERMEATE) is ADC2 but is used ONLY as a
 *  digital hardware interrupt — NOT analogRead(). This is safe.
 * ============================================================
 */

#ifndef CONFIG_H
#define CONFIG_H

// ============================================================
// FIRMWARE VERSION
// ============================================================
#define FIRMWARE_VERSION        "1.1.0"
#define DEVICE_ID               "device_001"
#define DEVICE_NAME             "RO Unit Alpha"

// ============================================================
// ANALOG SENSOR PINS  (ADC1 ONLY — WiFi-safe)
// ============================================================
//  GPIO34 (ADC1_CH6) — pH Feed
//  GPIO35 (ADC1_CH7) — TDS Feed
//  GPIO32 (ADC1_CH4) — Turbidity Feed
//  GPIO33 (ADC1_CH5) — Pressure Feed (G1/4, via 10kΩ/20kΩ divider)
//  GPIO36 (VP/ADC1_CH0) — pH Permeate
//  GPIO39 (VN/ADC1_CH3) — TDS Permeate
//  (Turbidity Permeate not wired — only one turbidity sensor on feed line)
#define PIN_PH_FEED             34      // ADC1_CH6 — pH feed analog output
#define PIN_TDS_FEED            35      // ADC1_CH7 — TDS feed analog output
#define PIN_TURBIDITY_FEED      32      // ADC1_CH4 — Turbidity feed (5V via 10kΩ/20kΩ divider)
#define PIN_PRESSURE_FEED       33      // ADC1_CH5 — Pressure sensor G1/4 (5V via 10kΩ/20kΩ divider)
#define PIN_PH_PERMEATE         36      // ADC1_CH0 (VP) — pH permeate analog output
#define PIN_TDS_PERMEATE        39      // ADC1_CH3 (VN) — TDS permeate analog output

// ============================================================
// DIGITAL SENSOR PINS
// ============================================================
#define PIN_DS18B20             4       // OneWire — DS18B20 temperature data
#define PIN_WATER_LEVEL_FEED    5       // Digital IN — XKC-Y25 feed tank
#define PIN_WATER_LEVEL_PRODUCT 19      // Digital IN — XKC-Y25 product tank
#define PIN_FLOW_SENSOR         18      // Interrupt — YF-S201 flow feed pulse
#define PIN_FLOW_PERMEATE       27      // Interrupt — YF-S201 flow permeate pulse

// ============================================================
// ACTUATOR PINS (RELAY MODULE)
// ============================================================
#define PIN_RELAY_PUMP          26      // Digital OUT — RO Pump relay
#define PIN_RELAY_VALVE         25      // Digital OUT — Solenoid Valve relay

// ============================================================
// STATUS LED
// ============================================================
#define PIN_STATUS_LED          2       // Built-in LED

// ============================================================
// RELAY LOGIC (Change if relay module is Active-HIGH)
// ============================================================
#define RELAY_ON                LOW     // Most relay modules are Active-LOW
#define RELAY_OFF               HIGH

// ============================================================
// ADC CONFIGURATION
// ============================================================
#define ADC_RESOLUTION          4095    // 12-bit ADC (0-4095)
#define ADC_VREF                3.3f    // ESP32 ADC reference voltage (V)
#define ADC_SAMPLES             10      // Oversampling count per reading
#define ADC_SAMPLE_DELAY_MS     2       // Delay between oversamples (ms)

// ============================================================
// VOLTAGE DIVIDER COMPENSATION
// ============================================================
// Turbidity & Pressure sensors output 0-4.5V (5V powered)
// Voltage divider: R1=10kΩ series, R2=20kΩ to GND
// Vout = Vin × (20/(10+20)) = Vin × 0.6667
// To recover original: Vin = Vout / 0.6667 × 1.0
#define VDIV_RATIO_TURBIDITY    1.5f    // Multiply ADC voltage by this to get actual sensor voltage
// Pressure sensor G1/4: outputs 0.5-4.5V at 5V supply (10k/20k divider: ×1.5 recovery)
#define VDIV_RATIO_PRESSURE     1.5f    // Same divider as turbidity
// pH sensor: direct 0-3.3V output (no divider needed on this kit)
#define VDIV_RATIO_PH           1.0f
// TDS sensor V1.0: max output 2.3V (no divider needed)
#define VDIV_RATIO_TDS          1.0f
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

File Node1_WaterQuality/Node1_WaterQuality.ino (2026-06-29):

/*
 * ============================================================
 *  Smart Water Desalination Monitoring System
 *  Firmware: Node 1 — Water Quality
 *  Version:  1.2.0
 *  Role:     Reads pH (feed+permeate), TDS (feed+permeate),
 *            Turbidity (feed), Temperature (feed+permeate),
 *            Pressure (feed), Flow (feed+permeate), Level (feed+product).
 *            Controls RO Pump & Solenoid Valve relays.
 *            Transmits data to Firebase via WiFi every 5 seconds.
 *            Broadcasts full sensor struct to Main Hub via ESP-NOW.
 *  Phase:    3 — ESP32 Firmware Development
 * ============================================================
 */

#include "config.h"
#include "state_machine.h"
#include "espnow_broadcast.h"
#include <Arduino.h>

StateMachine stateMachine;

volatile uint32_t flowFeedPulseCount = 0;
volatile uint32_t flowPermeatePulseCount = 0;

void IRAM_ATTR flowFeedPulseISR() {
    flowFeedPulseCount++;
}

void IRAM_ATTR flowPermeatePulseISR() {
    flowPermeatePulseCount++;
}

void setup() {
    Serial.begin(SERIAL_BAUD_RATE);
    delay(1000);

    DEBUG_PRINTLN("\n=============================================");
    DEBUG_PRINTF("🚀 %s starting...\n", DEVICE_NAME);
    DEBUG_PRINTF("Firmware Version: %s\n", FIRMWARE_VERSION);
    DEBUG_PRINTLN("=============================================");

    // Initialize GPIO for basic needs before state machine handles complex init
    pinMode(PIN_STATUS_LED, OUTPUT);
    pinMode(PIN_RELAY_PUMP, OUTPUT);
    pinMode(PIN_RELAY_VALVE, OUTPUT);
    pinMode(PIN_WATER_LEVEL_FEED, INPUT_PULLUP);
    pinMode(PIN_WATER_LEVEL_PRODUCT, INPUT_PULLUP);
    pinMode(PIN_FLOW_SENSOR, INPUT_PULLUP);
    pinMode(PIN_FLOW_PERMEATE, INPUT_PULLUP);

    // Initial safe state
    digitalWrite(PIN_RELAY_PUMP, RELAY_OFF);
    digitalWrite(PIN_RELAY_VALVE, RELAY_OFF);

    // ADC setup
    analogReadResolution(12);
    analogSetAttenuation(ADC_11db);

    // Interrupts
    attachInterrupt(digitalPinToInterrupt(PIN_FLOW_SENSOR), flowFeedPulseISR, FALLING);
    attachInterrupt(digitalPinToInterrupt(PIN_FLOW_PERMEATE), flowPermeatePulseISR, FALLING);

    stateMachine.begin();
}

void loop() {
    stateMachine.tick();
}

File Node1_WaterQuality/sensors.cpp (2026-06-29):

#include "sensors.h"
#include "filters.h"
#include <OneWire.h>
#include <DallasTemperature.h>

// ============================================================
// Kalman Filters (pH & TDS — high-noise analog sensors)
// ============================================================
KalmanFilter phFeedKalman(KALMAN_Q, KALMAN_R, 1.0f, 7.0f);
KalmanFilter phPermeateKalman(KALMAN_Q, KALMAN_R, 1.0f, 7.0f);
KalmanFilter tdsFeedKalman(KALMAN_Q, KALMAN_R, 1.0f, 0.0f);
KalmanFilter tdsPermeateKalman(KALMAN_Q, KALMAN_R, 1.0f, 0.0f);

// ============================================================
// Moving Average Filters (Flow Rate)
// ============================================================
MovingAverage flowFeedAvg(FLOW_AVG_WINDOW);
MovingAverage flowPermeateAvg(FLOW_AVG_WINDOW);

// ============================================================
// OneWire & DallasTemperature (DS18B20)
// Two sensors on the same bus: index 0 = feed, index 1 = permeate
// ============================================================
OneWire oneWire(PIN_DS18B20);
DallasTemperature ds18b20(&oneWire);

// ============================================================
// Sensor Initialisation
// ============================================================
void sensorsInit() {
    ds18b20.begin();
    ds18b20.setResolution(DS18B20_RESOLUTION);
    flowFeedAvg.reset();
    flowPermeateAvg.reset();
}

// ============================================================
// ADC Helper — Oversampled average (reduces quantisation noise)
// ============================================================
float readADC_Voltage(uint8_t pin, uint8_t samples) {
    uint32_t sum = 0;
    for (uint8_t i = 0; i < samples; i++) {
        sum += analogRead(pin);
        delay(ADC_SAMPLE_DELAY_MS);
    }
    return ((float)sum / samples / ADC_RESOLUTION) * ADC_VREF;
}

// ============================================================
// pH Sensor — Analog kit (0–14 pH, 0–5V output)
// ============================================================
float readPH(uint8_t pin, KalmanFilter& filter, float temperature) {
    float voltage = readADC_Voltage(pin);
    voltage *= VDIV_RATIO_PH;
    // pH calibration line: pH = 7 + (V - V@pH7) / slope
    float ph = 7.0f + ((voltage - PH_VOLTAGE_AT_PH7) / PH_SLOPE);
    // Nernst equation temperature compensation
    ph = ph + (25.0f - temperature) * PH_TEMP_COEFFICIENT;
    // Clamp to physically meaningful range
    ph = constrain(ph, 0.0f, 14.0f);
    return filter.update(ph);
}

// ============================================================
// TDS Sensor V1.0 — Analog (0–1000 ppm, max 2.3V output)
// ============================================================
float readTDS(uint8_t pin, KalmanFilter& filter, float temperature) {
    float voltage = readADC_Voltage(pin);
    voltage *= VDIV_RATIO_TDS;
    
    // Temperature compensation
    float compensationCoefficient = 1.0f + TDS_TEMP_COEFFICIENT * (temperature - TDS_REFERENCE_TEMP);
    float compensationVoltage = voltage / compensationCoefficient;
    
    // Polynomial voltage-to-TDS conversion (manufacturer curve fit)
    float tdsValue = (133.42f * compensationVoltage * compensationVoltage * compensationVoltage 
                      - 255.86f * compensationVoltage * compensationVoltage 
                      + 857.39f * compensationVoltage) * 0.5f;
                      
    if (tdsValue < 0) tdsValue = 0;
    return filter.update(tdsValue);
}

// ============================================================
// Turbidity Sensor — Analog (0–3000 NTU, 0–4.5V output @ 5V)
// Requires 10kΩ/20kΩ voltage divider (VDIV_RATIO_TURBIDITY = 1.5)
// ============================================================
float readTurbidity(uint8_t pin) {
    float voltage = readADC_Voltage(pin);
    voltage *= VDIV_RATIO_TURBIDITY; // Recover actual sensor voltage

    // Inverse relationship: higher voltage = clearer water
    float ntu = (TURBIDITY_VOLTAGE_CLEAR - voltage) * TURBIDITY_SLOPE;
    if (ntu < 0) ntu = 0;
    return ntu;
}

// ============================================================
// Pressure Sensor G1/4 — Analog (0–1.2 MPa / 0–12 bar, 0.5–4.5V @ 5V)
// Requires 10kΩ/20kΩ voltage divider (VDIV_RATIO_PRESSURE = 1.5)
// ============================================================
float readPressure(uint8_t pin) {
    float voltage = readADC_Voltage(pin);
    voltage *= VDIV_RATIO_PRESSURE; // Recover actual sensor voltage

    // Linear conversion: P(bar) = (Vin - 0.5V) / (4.5V - 0.5V) × MAX_BAR
    float pressureBar = (voltage - PRESSURE_OFFSET_V) / (PRESSURE_SCALE_V - PRESSURE_OFFSET_V) * PRESSURE_MAX_BAR;
    if (pressureBar < 0) pressureBar = 0;
    return pressureBar;
}

// ============================================================
// DS18B20 Temperature — OneWire (−55 to +125°C)
// Call ds18b20.requestTemperatures() before reading!
// ============================================================
float readTemperature(uint8_t index) {
    float tempC = ds18b20.getTempCByIndex(index);
    if (tempC == DEVICE_DISCONNECTED_C) {
        DEBUG_PRINTF("DS18B20[%d] disconnected, using fallback 25°C\n", index);
        return 25.0f;
    }
    return tempC;
}

// ============================================================
// Flow Rate — YF-S201 (1–30 L/min, interrupt-counted pulses)
// intervalMs: time window over which pulses were counted
// ============================================================
float readFlowRate(MovingAverage& avgFilter, uint32_t pulseCount, uint32_t intervalMs) {
    float pulsesPerSec = ((float)pulseCount * 1000.0f) / (float)intervalMs;
    float lPerMin = pulsesPerSec / FLOW_CALIBRATION_FACTOR;
    return avgFilter.update(lPerMin);
}

// ============================================================
// Water Level — XKC-Y25 Non-Contact (Digital HIGH/LOW)
// INPUT_PULLUP: LOW = water present, HIGH = empty
// ============================================================
WaterLevelState readWaterLevel(uint8_t pin) {
    return (digitalRead(pin) == LOW) ? LEVEL_WATER : LEVEL_EMPTY;
}
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
